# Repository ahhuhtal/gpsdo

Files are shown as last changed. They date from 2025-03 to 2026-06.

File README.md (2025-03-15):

# GPS discliplined oscillator

Contained in this repository are the source code and PCB design files for my GPS disciplined oscillator project.

The GPSDO uses the one pulse per second (PPS) output of a GPS receiver to continuously adjust an OSC5A2B02 oven-controller crystal oscillator to keep it phase-locked with GPS time.

This gives a stable (both short term and long) 10 MHz time base for measurement instruments.

An important design goal has been to keep the cost very low.

Some more information is available at https://kiedontaa.blogspot.com/2025/02/gps-disciplined-oscillator-part-2.html

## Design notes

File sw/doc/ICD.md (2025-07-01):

# Interface control documentation

Several messages pass between the components of the GPSDO system. The contents of those messages are described here.

## I2C

I2C messages are passed between the 4 microcontrollers which make up the system. Each controller has the ability to pull data from or push data to other controllers (act as a master), or have data pushed to or pulled from them (act as a slave).

Fields are described in the order they are transferred. All multi-byte fields are transferred as little-endian. All structures are packed without padding. 

### PPS message

- Type: master push
- 8-bit address: 0x10
- Master: `iface`
- Slave: `pfd`

Message structure:
```
uint32_t timestamp
uint8_t fix
```

`timestamp` is the unix timestamp of the received PPS pulse (seconds since 1970-01-01).

`fix` is 1 when the PPS was produced with full GNSS position fix. Any other value indicates that the PPS was produced without a valid fix.

### OCXO control message

- Type: master push
- 8-bit address: 0x0c
- Master: `pfd`
- Slave: `ocxo_ctrl`

Message structure:
```
int16_t control_word
```

`control_word` determines the frequency adjustment applied to the OCXO. The full scale is available for adjustment. An LSB corresponds with approximately 115 microHertz of frequency adjustment, or about 19 microvolts of control voltage.

### GNSS status message

- Type: master pull
- 8-bit address: 0x03
- Master: `lcd`
- Slave: `iface`

Message structure:
```
uint32_t timestamp
int32_t latitude
int32_t longitude
uint8_t nsat_fix_valid
```

`timestamp` is the unix timestamp of the last GNSS position fix (seconds since 1970-01-01).

`latitude` and `longitude` are the latitude and longitude of the last GNSS position fix as a fraction of 360 degrees, given in fixed point Q0.31 format (sign bit and 31 bits of fraction). Example: `degrees_latitude = latitude / 2**31 * 360.0`. Positive values of `latitude` indicate North, while positive values of `longitude` indicate East. 

Bit 7 of `nsat_fix_valid` indicates validity of the message. The message becomes invalid if the contents are older than 4 seconds.

Bit 6 of `nsat_fix_valid` indicates whether a GNSS position fix is valid (1) or not (0). A valid fix means that the latitude, longitude and timestamp values are valid.

Bits[5:0] of `nsat_fix_valid` indicate the number of satellites used in the last position fix. The value is interpreted as an unsigned integer in the range 0-63.

### Timing status message

- Type: master pull
- 8-bit address: 0x11
- Master: `lcd`
- Slave: `pfd`

Message structure:
```
int32_t phase_error_raw
int32_t phase_error_filtered
int32_t frequecy_error_raw
int32_t frequency_error_filtered
uint32_t time_since_valid
int16_t ocxo_control_word
uint8_t control_mode
```

`phase_error_raw` is the raw estimated phase error from the latest estimation period. `phase_error_filtered` is the filtered phase error, which is a low-pass filtered version of `phase_error_raw`. Both values are in fixed point Q7.24 format (sign bit, 7 bits of integer and 24 bits of fraction). The LSB of these values is approximately 3.0 fs (femtoseconds).

`frequency_error_raw` is the raw estimated frequency error from the latest estimation period. `frequency_error_filtered` is the filtered frequency error, which is a low-pass filtered version of `frequency_error_raw`. Both values are in fixed point Q7.24 format (sign bit, 7 bits of integer and 24 bits of fraction). The LSB of these values is approximately 29.8 nHz (nanohertz).

`time_since_valid` is the time in seconds since a PPS pulse passed full validation.

`ocxo_control_word` is the latest control word sent to the OCXO controller. It is in the same format as the `control_word` field of the OCXO control message.

`control_mode` indicates the current control mode of the system. A value of 0 indicates that the system is in FLL mode, while a value of 1 indicates that the system is in PLL mode. The system starts up in FLL mode and switches to PLL mode once the frequency error has been sufficiently reduced.

### OCXO status message

- Type: master pull
- 8-bit address: 0x0d
- Master: `lcd`
- Slave: `ocxo_ctrl`

Message structure:
```
int16_t temperature
```

`temperature` is the measured temperature of the OCXO. It is in Q11.4 format (sign bit, 11 bits of integer part, 4 bits of fraction) and is given in degrees Celsius. The LSB of this value is 0.0625 degrees Celsius. Example: `temperature_degrees = temperature / 16.0`.

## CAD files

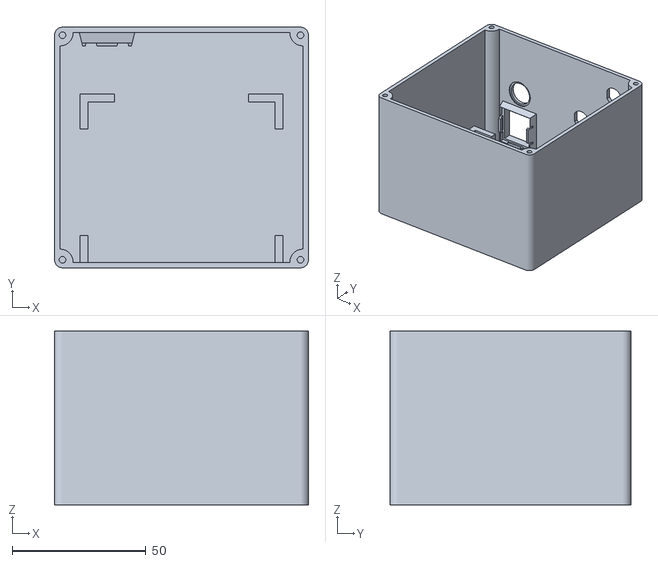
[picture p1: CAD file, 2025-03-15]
mechanics/main_unit/box_bottom.stl
95.0 x 90.0 x 65.0

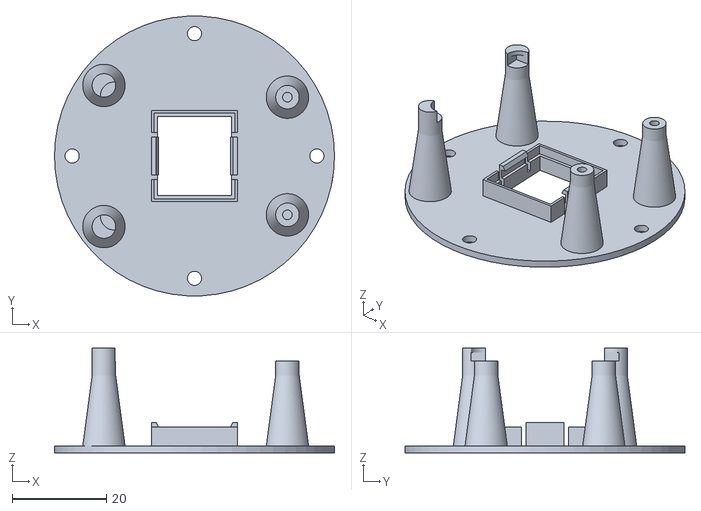
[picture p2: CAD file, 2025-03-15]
mechanics/receiver_unit/bottom_plate.stl
59.5 x 59.4 x 22.3

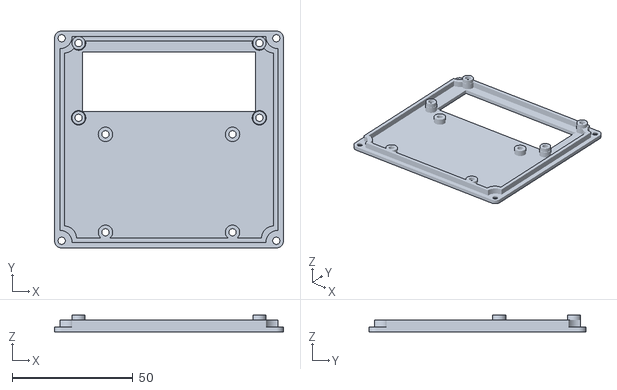
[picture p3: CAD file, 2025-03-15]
mechanics/main_unit/box_lid.stl
95.0 x 90.0 x 7.00

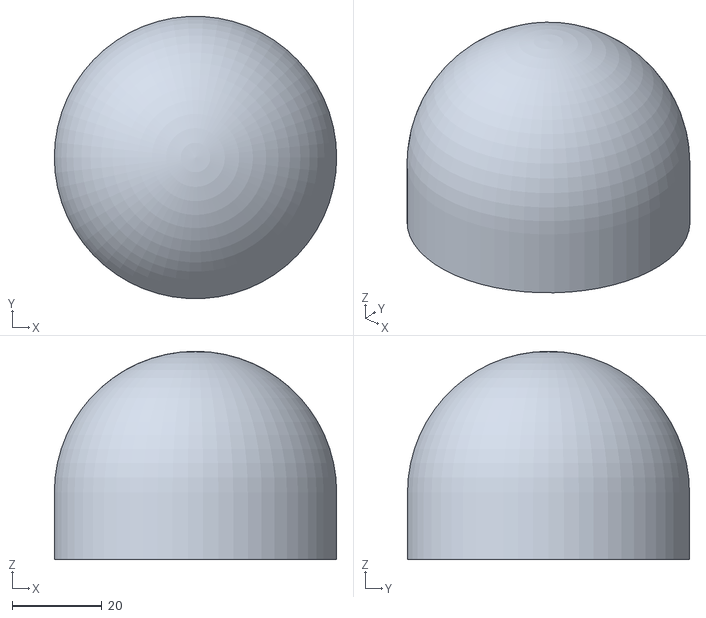
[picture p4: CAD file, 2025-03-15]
mechanics/receiver_unit/dome.stl
63.0 x 62.9 x 46.5

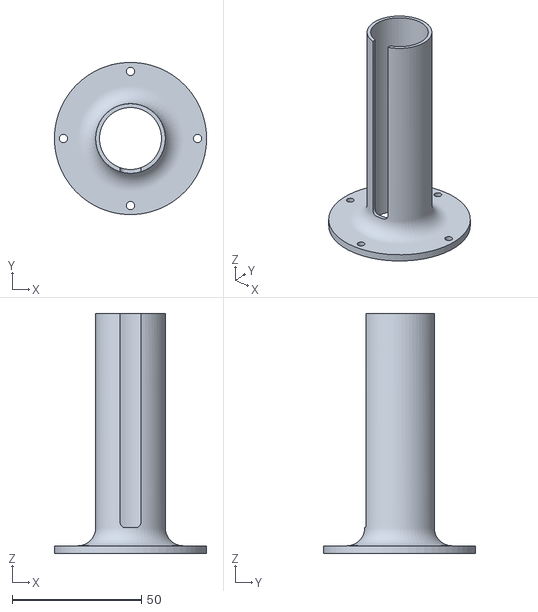
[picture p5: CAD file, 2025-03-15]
mechanics/receiver_unit/pole_mount.stl
59.0 x 58.9 x 93.0

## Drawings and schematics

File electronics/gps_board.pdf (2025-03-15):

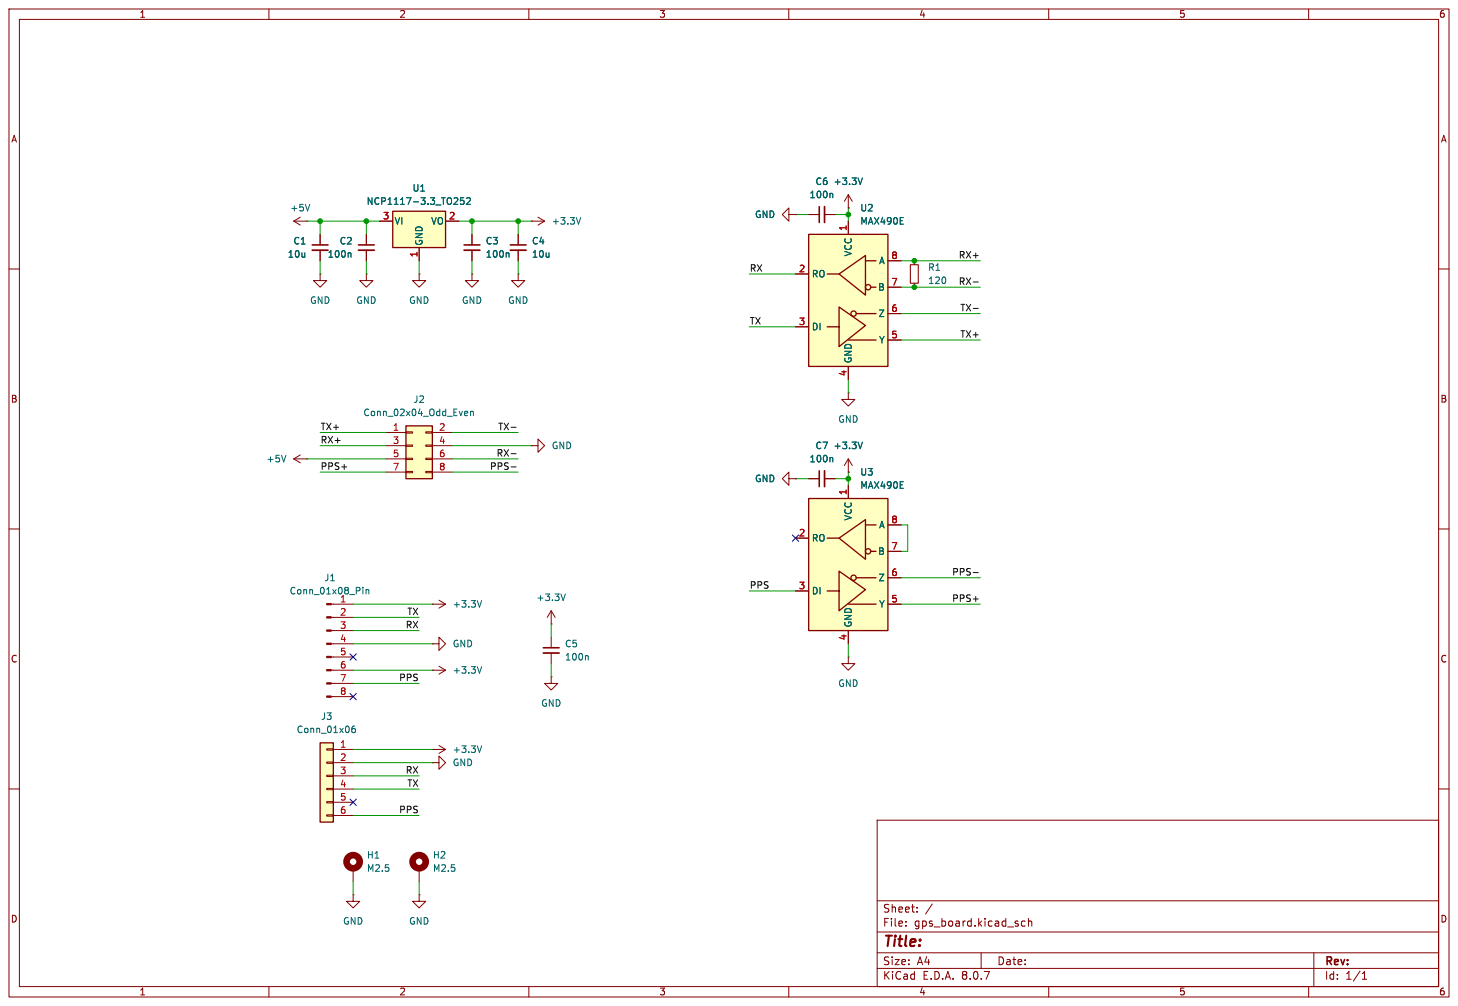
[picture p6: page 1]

Id: 1/1 Title: File: gps_board.kicad_sch Sheet: / H1 M2.5

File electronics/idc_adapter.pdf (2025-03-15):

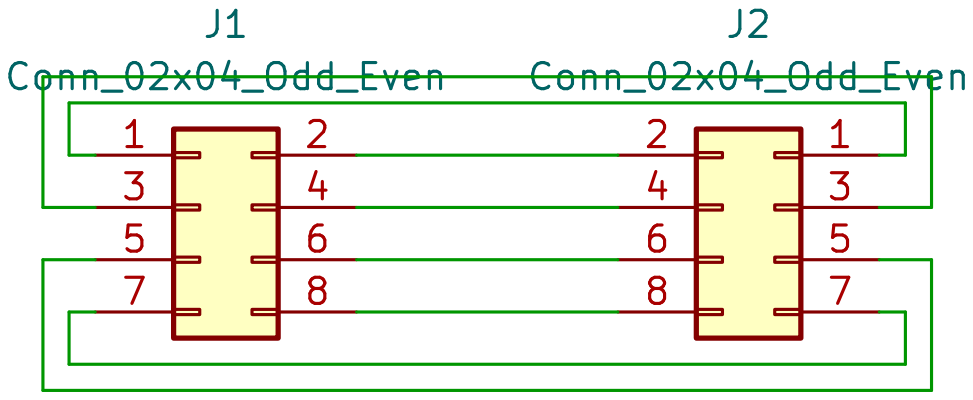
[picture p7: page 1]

Id: 1/1 Title: File: idc_adapter.kicad_sch Sheet: /

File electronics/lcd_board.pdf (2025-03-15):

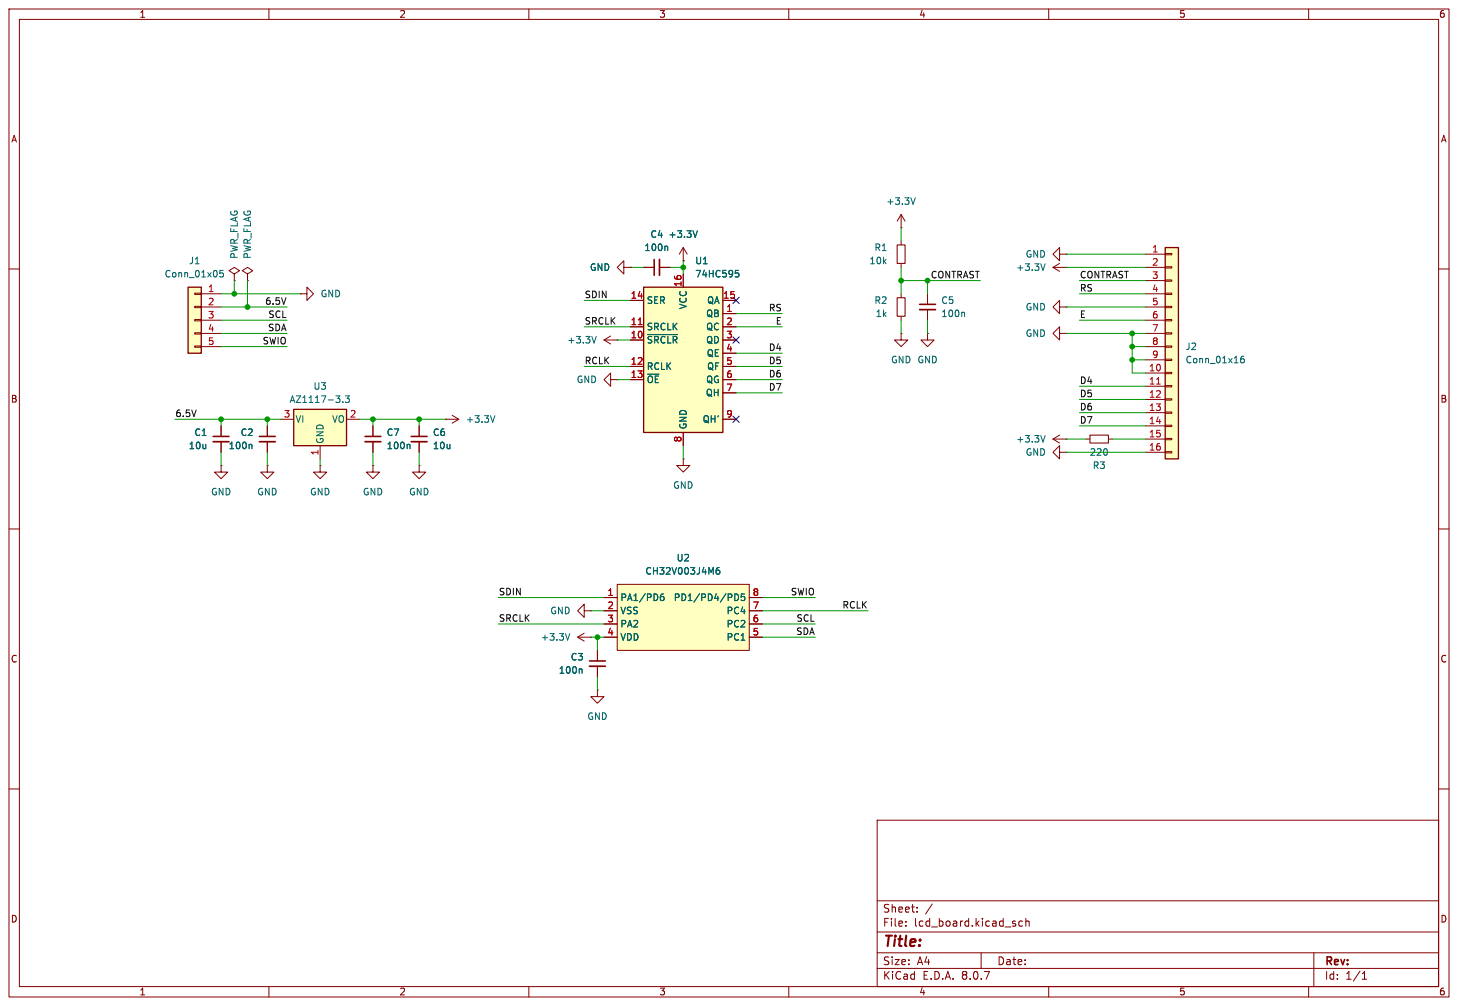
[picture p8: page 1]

Id: 1/1 Title: File: lcd_board.kicad_sch Sheet: /

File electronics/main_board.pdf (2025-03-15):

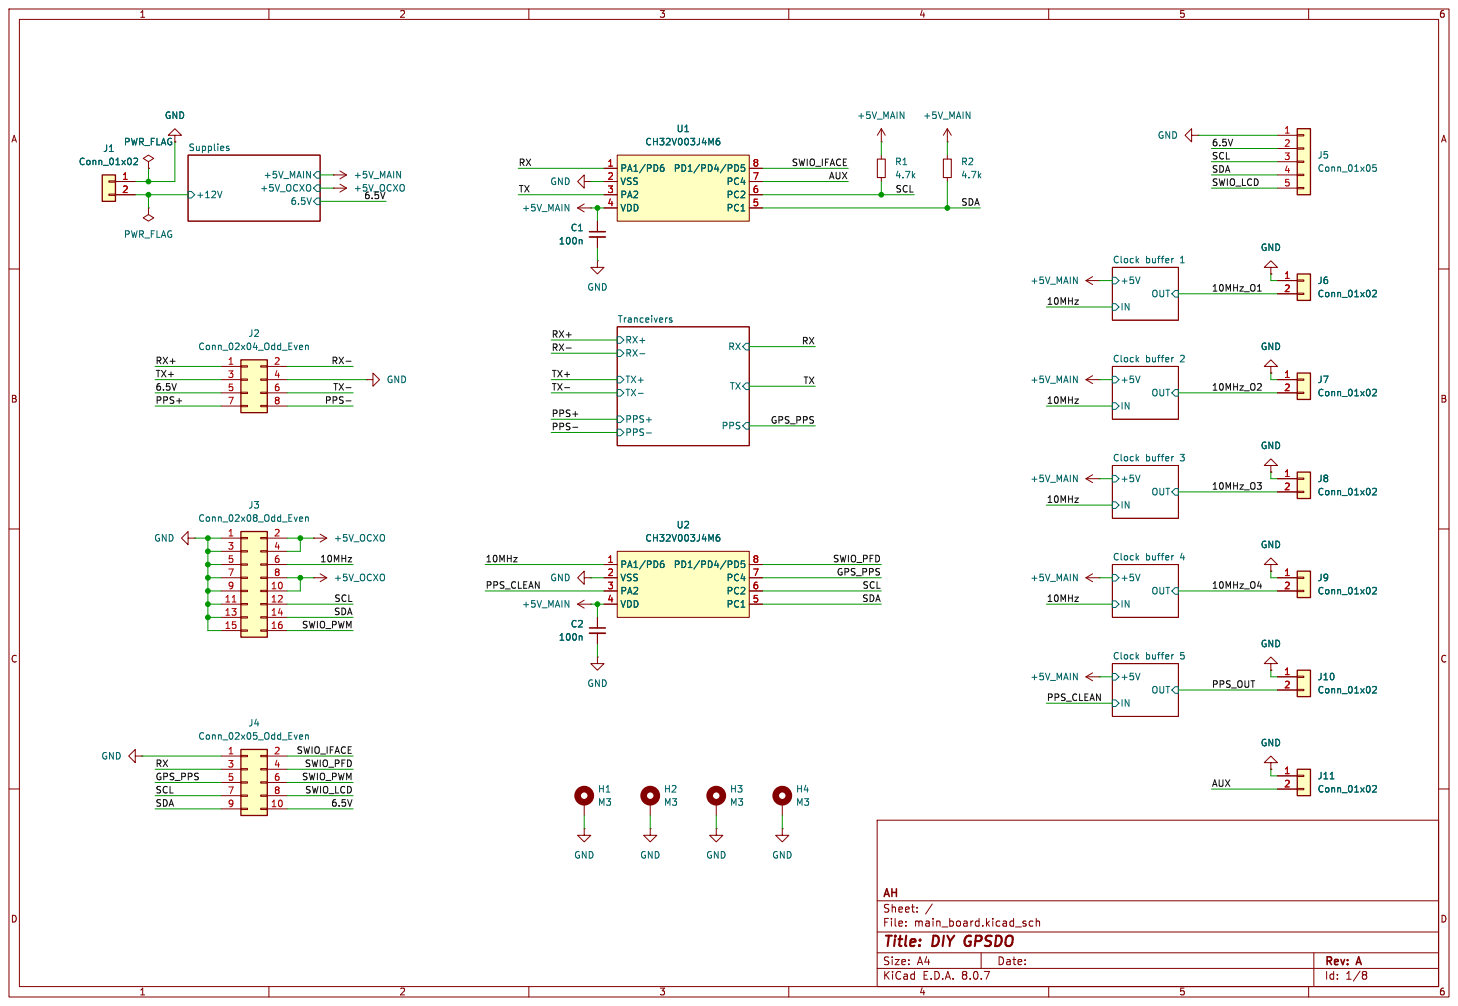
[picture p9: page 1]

Id: 1/8 Title: DIY GPSDO

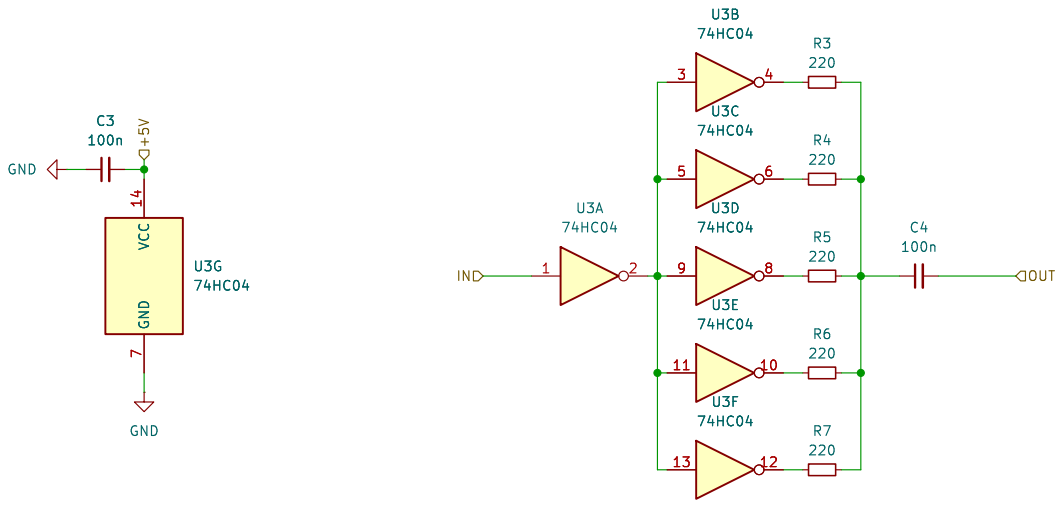
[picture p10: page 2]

Id: 2/8 Title: DIY GPSDO

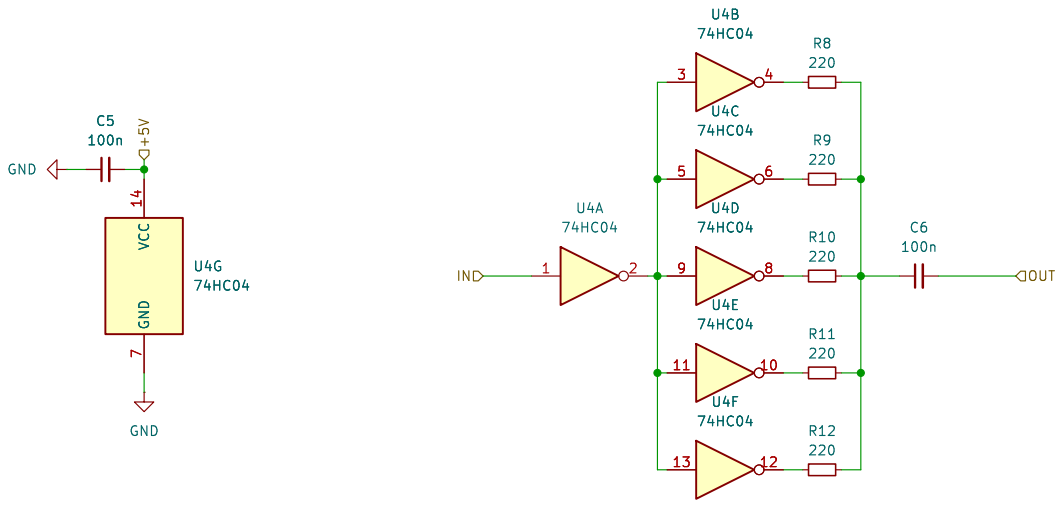
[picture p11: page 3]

Id: 3/8 Title: DIY GPSDO

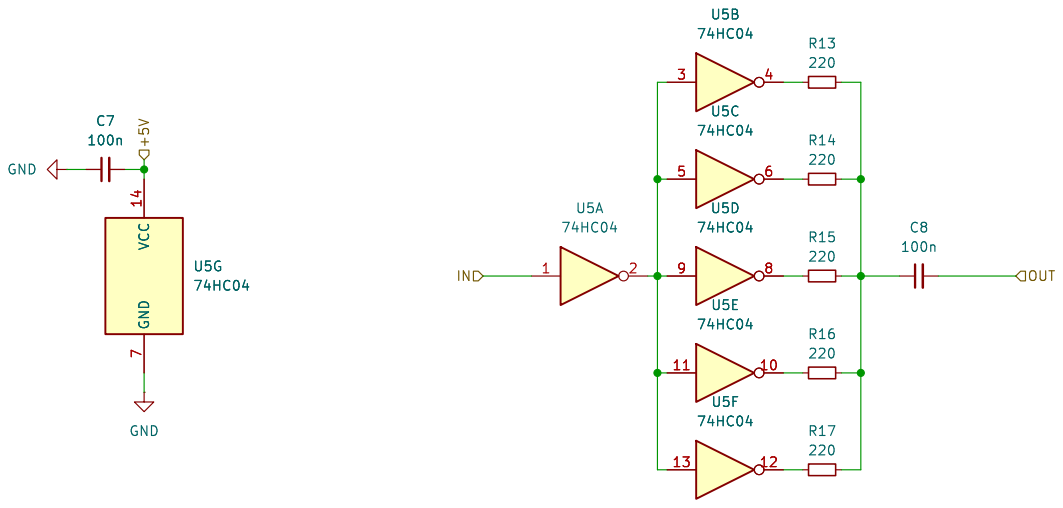
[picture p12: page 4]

Id: 4/8 Title: DIY GPSDO

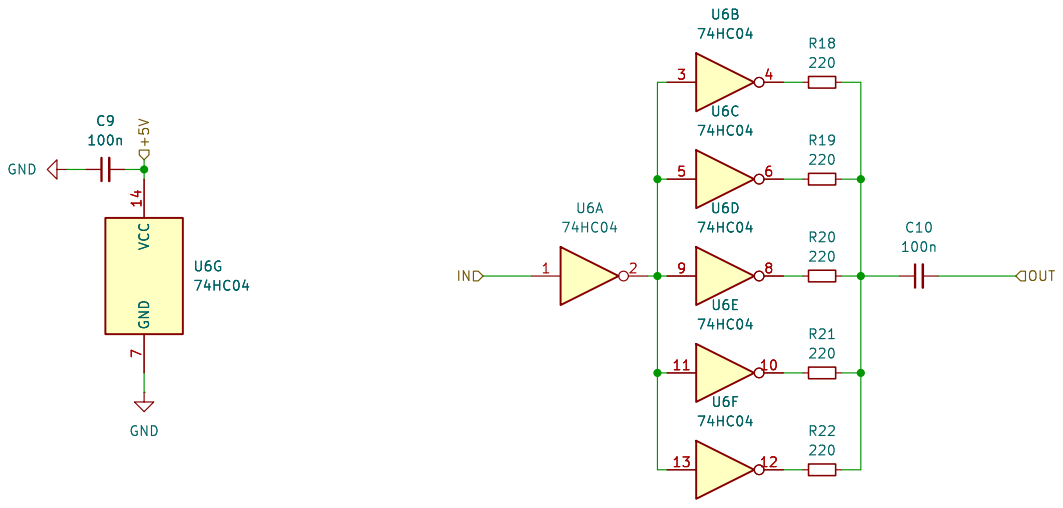
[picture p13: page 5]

Id: 5/8 Title: DIY GPSDO

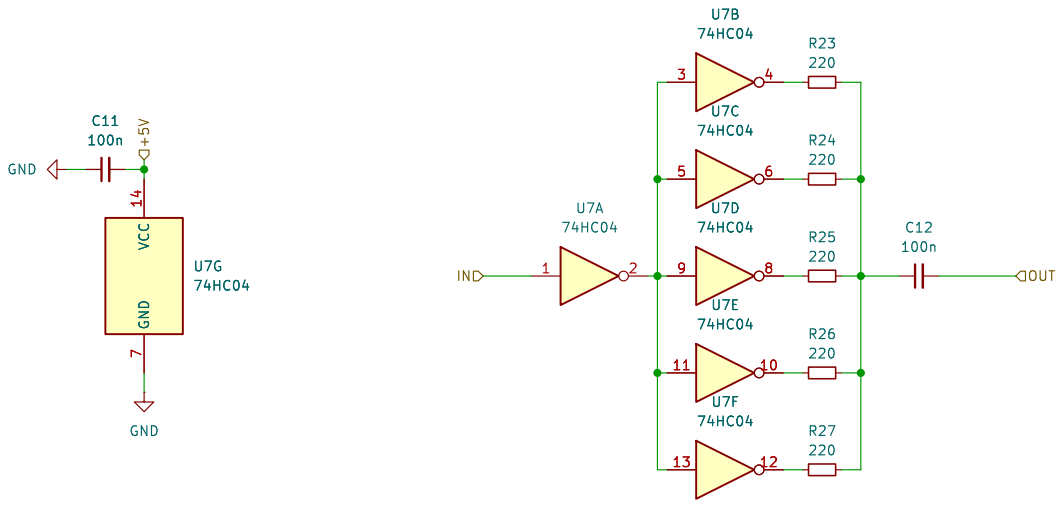
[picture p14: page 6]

Id: 6/8 Title: DIY GPSDO

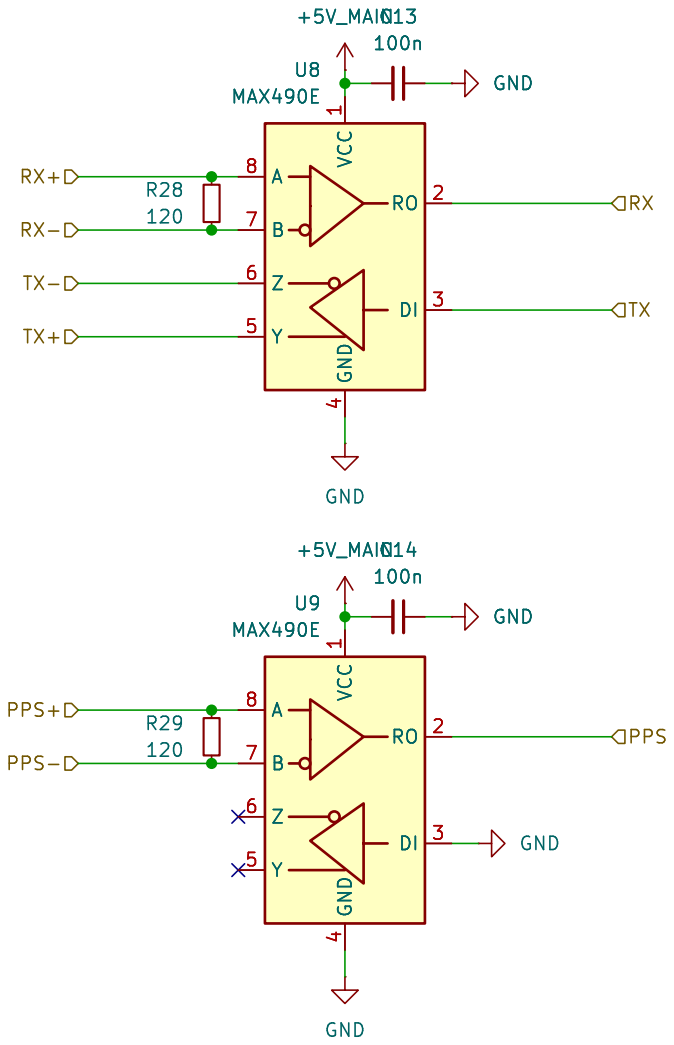
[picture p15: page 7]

Id: 7/8 Title: DIY GPSDO

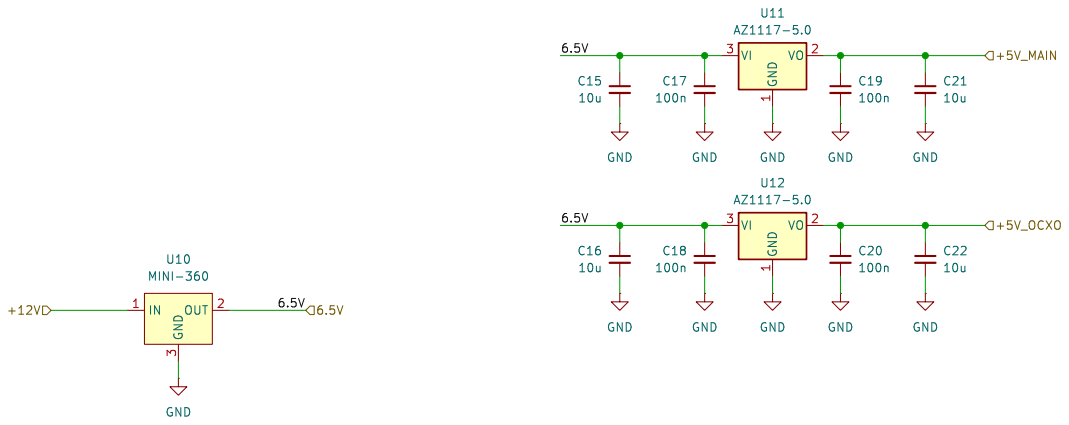
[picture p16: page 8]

1 VO 2 VI 3 U11 AZ1117-5.0 GND GND

Power supplies
File: supplies.kicad_sch Sheet: /Supplies/ AH

Id: 8/8 Title: DIY GPSDO

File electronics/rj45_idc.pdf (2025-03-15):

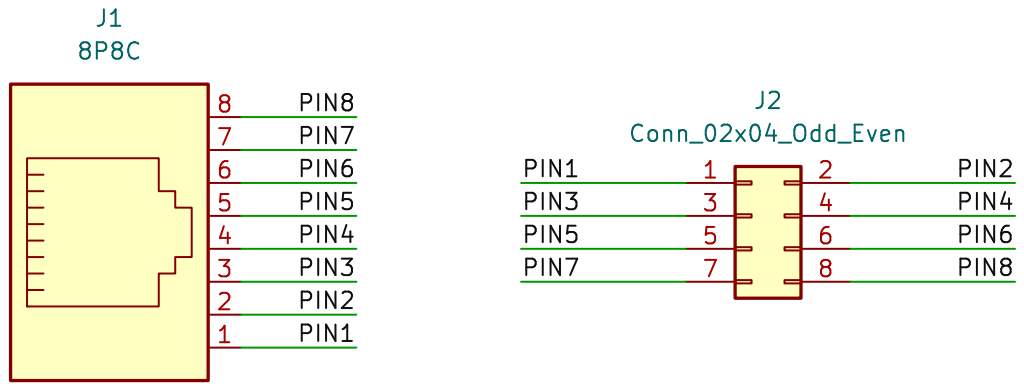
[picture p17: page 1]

Id: 1/1 Title: File: rj45_idc.kicad_sch Sheet: /


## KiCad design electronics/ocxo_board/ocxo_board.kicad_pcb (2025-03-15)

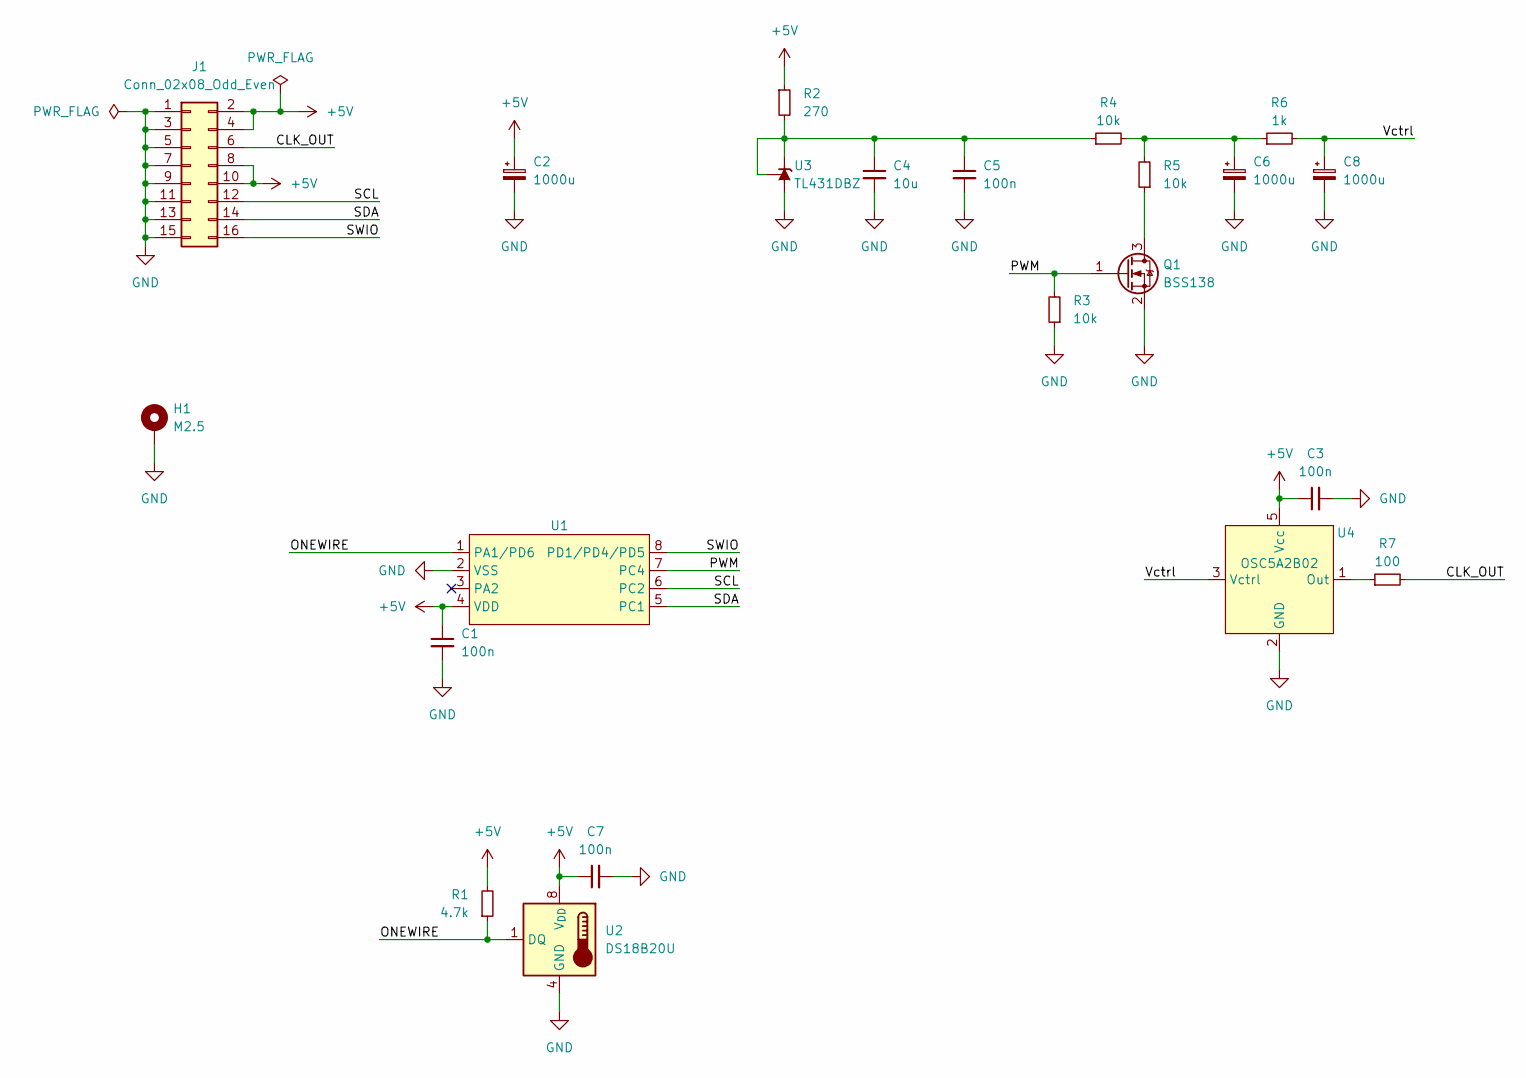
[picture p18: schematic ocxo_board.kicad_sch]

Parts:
C1, C3, C5, C7: 100n; C_0805_2012Metric_Pad1.18x1.45mm_HandSolder
C2, C6, C8: 1000u; CP_Radial_D8.0mm_P3.50mm
C4: 10u; C_0805_2012Metric_Pad1.18x1.45mm_HandSolder
H1: M2.5; MountingHole_2.7mm_M2.5_DIN965_Pad
J1: Conn_02x08_Odd_Even; IDC-Header_2x08_P2.54mm_Vertical
Q1: BSS138; SOT-23
R1: 4.7k; R_0805_2012Metric_Pad1.20x1.40mm_HandSolder
R2: 270; R_0805_2012Metric_Pad1.20x1.40mm_HandSolder
R3, R4, R5: 10k; R_0805_2012Metric_Pad1.20x1.40mm_HandSolder
R6: 1k; R_0805_2012Metric_Pad1.20x1.40mm_HandSolder
R7: 100; R_0805_2012Metric_Pad1.20x1.40mm_HandSolder
U1: SOP-8_3.9x4.9mm_P1.27mm
U2: DS18B20U; MSOP-8_3x3mm_P0.65mm
U3: TL431DBZ; SOT-23
U4: OSC5A2B02

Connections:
+5V: C1.1, C2.1, C3.1, C7.1, J1.2, J1.4, J1.8, J1.10, R1.2, R2.1, U1.4 (VDD), U2.8 (V_{DD}), U4.5 (Vcc)
/CLK_OUT: J1.6, R7.2
/ONEWIRE: R1.1, U1.1 (PA1/PD6), U2.1 (DQ)
/PWM: Q1.1 (G), R3.2, U1.7 (PC4)
/SCL: J1.12, U1.6 (PC2)
/SDA: J1.14, U1.5 (PC1)
/SWIO: J1.16, U1.8 (PD1/PD4/PD5)
/Vctrl: C8.1, R6.2, U4.3 (Vctrl)
GND: C1.2, C2.2, C3.2, C4.2, C5.2, C6.2, C7.2, C8.2, H1.1, J1.1, J1.3, J1.5, J1.7, J1.9, J1.11, J1.13, J1.15, Q1.2 (S), R3.1, U1.2 (VSS), U2.4 (GND), U3.3 (A), U4.2 (GND)
unnamed: C6.1, R4.2, R5.2, R6.1
unnamed: Q1.3 (D), R5.1
unnamed: C4.1, C5.1, R2.2, R4.1, U3.1 (K), U3.2 (REF)
unnamed: R7.1, U4.1 (Out)

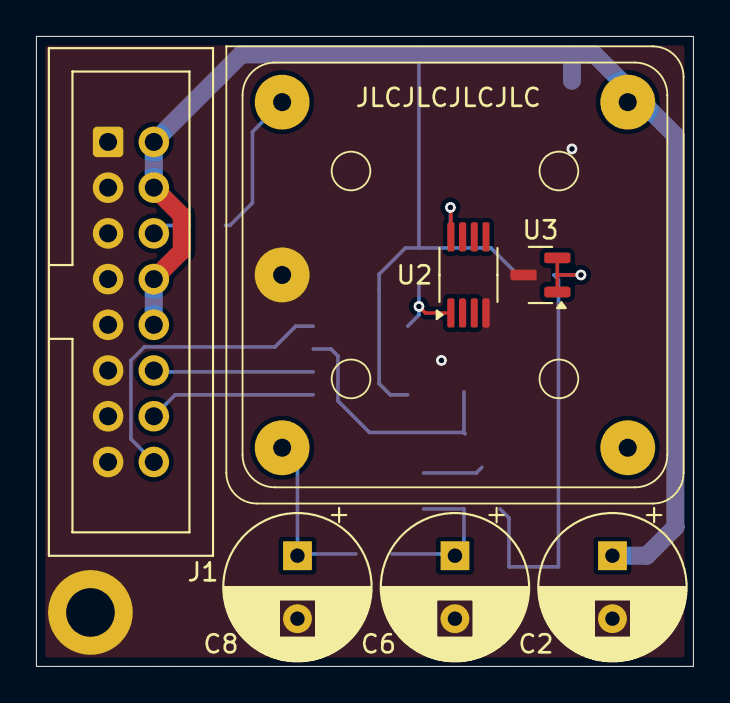
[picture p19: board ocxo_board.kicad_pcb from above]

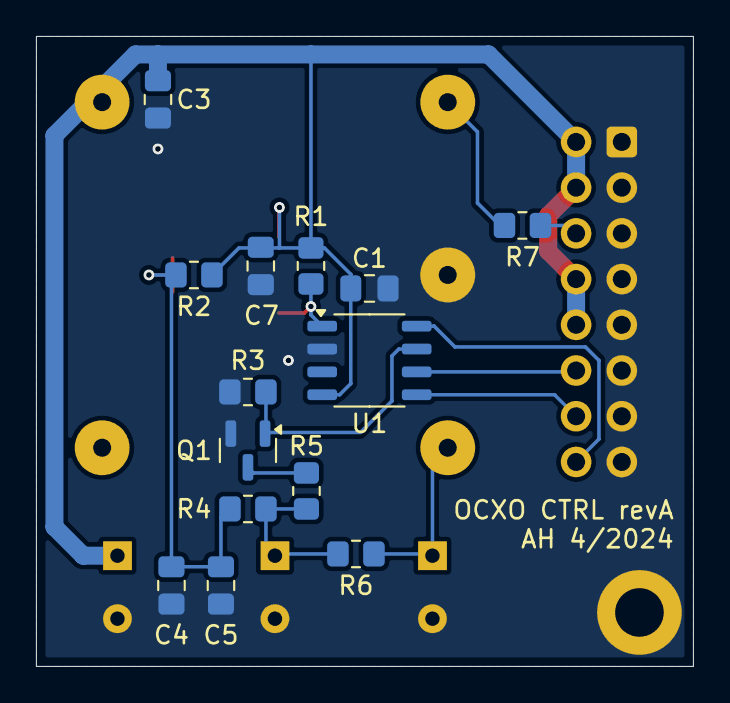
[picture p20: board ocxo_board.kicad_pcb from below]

Board: 2 copper layers, 36.5 x 35.0 mm, 22 parts (14 on the bottom side), 13 nets.

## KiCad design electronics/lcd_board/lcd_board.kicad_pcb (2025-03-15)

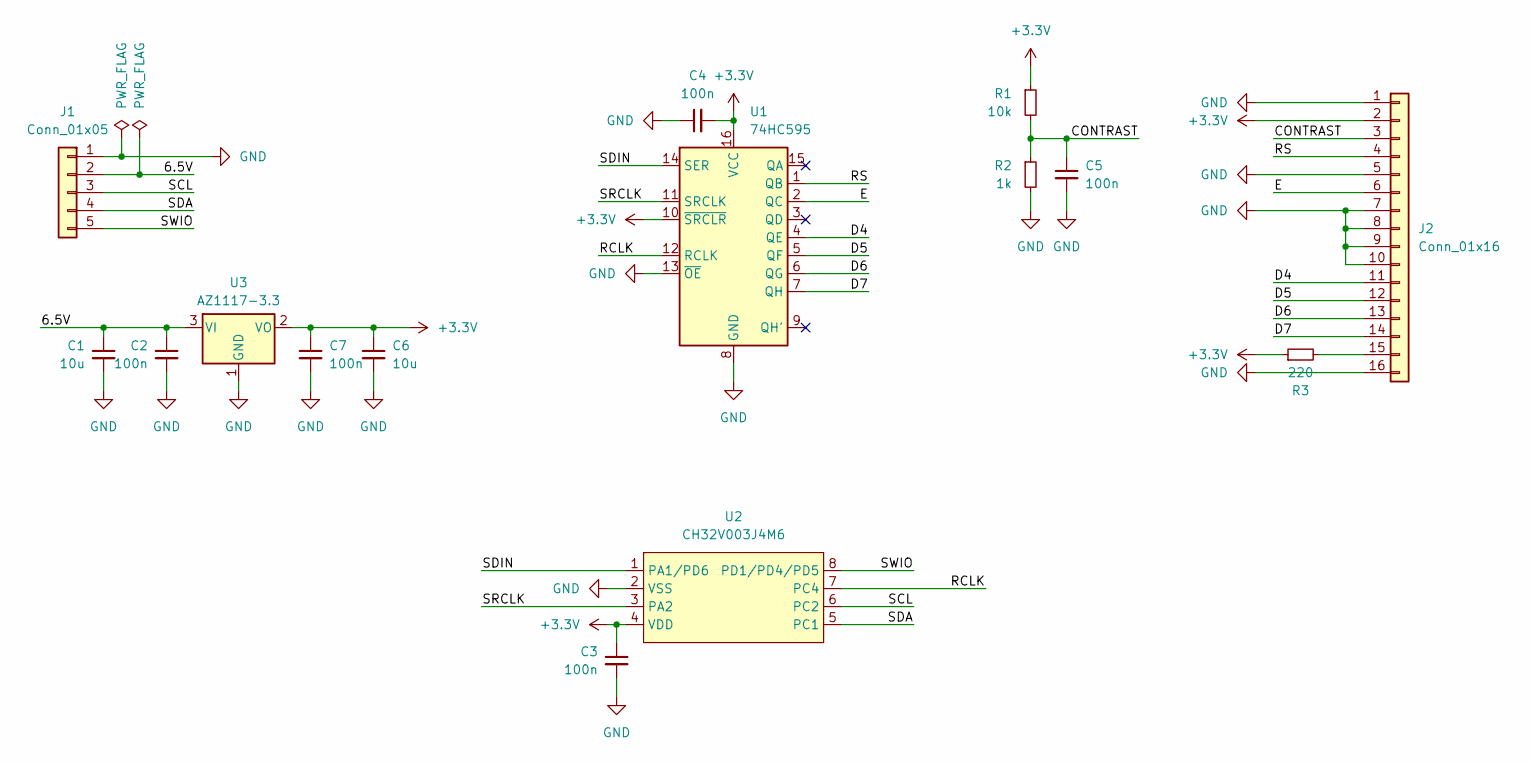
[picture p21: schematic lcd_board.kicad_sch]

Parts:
C1, C6: 10u; C_0805_2012Metric_Pad1.18x1.45mm_HandSolder
C2, C3, C4, C5, C7: 100n; C_0805_2012Metric_Pad1.18x1.45mm_HandSolder
J1: Conn_01x05; JST_PH_B5B-PH-K_1x05_P2.00mm_Vertical
J2: Conn_01x16; PinHeader_1x16_P2.54mm_Vertical
R1: 10k; R_0805_2012Metric_Pad1.20x1.40mm_HandSolder
R2: 1k; R_0805_2012Metric_Pad1.20x1.40mm_HandSolder
R3: 220; R_0805_2012Metric_Pad1.20x1.40mm_HandSolder
U1: 74HC595; SOIC-16_3.9x9.9mm_P1.27mm
U2: CH32V003J4M6; SOP-8_3.9x4.9mm_P1.27mm
U3: AZ1117-3.3; SOT-223-3_TabPin2

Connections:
+3.3V: C3.1, C4.2, C6.1, C7.1, J2.2, R1.1, R3.1, U1.10 (~SRCLR), U1.16 (VCC), U2.4 (VDD), U3.2 (VO)
/6.5V: C1.1, C2.1, J1.2, U3.3 (VI)
/CONTRAST: C5.1, J2.3, R1.2, R2.1
/D4: J2.11, U1.4 (QE)
/D5: J2.12, U1.5 (QF)
/D6: J2.13, U1.6 (QG)
/D7: J2.14, U1.7 (QH)
/E: J2.6, U1.2 (QC)
/RCLK: U1.12 (RCLK), U2.7 (PC4)
/RS: J2.4, U1.1 (QB)
/SCL: J1.3, U2.6 (PC2)
/SDA: J1.4, U2.5 (PC1)
/SDIN: U1.14 (SER), U2.1 (PA1/PD6)
/SRCLK: U1.11 (SRCLK), U2.3 (PA2)
/SWIO: J1.5, U2.8 (PD1/PD4/PD5)
GND: C1.2, C2.2, C3.2, C4.1, C5.2, C6.2, C7.2, J1.1, J2.1, J2.5, J2.7, J2.8, J2.9, J2.10, J2.16, R2.2, U1.8 (GND), U1.13 (~OE), U2.2 (VSS), U3.1 (GND)
unnamed: J2.15, R3.2

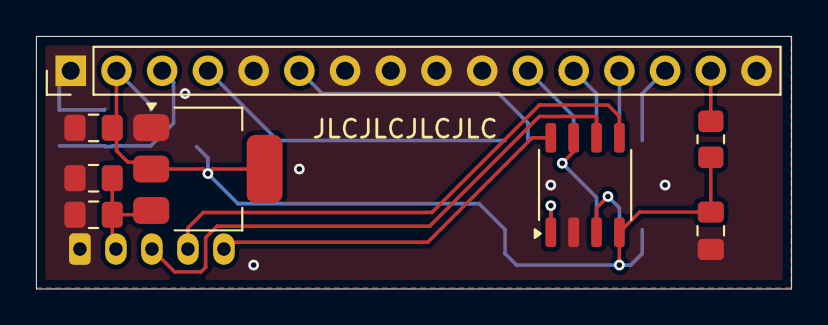
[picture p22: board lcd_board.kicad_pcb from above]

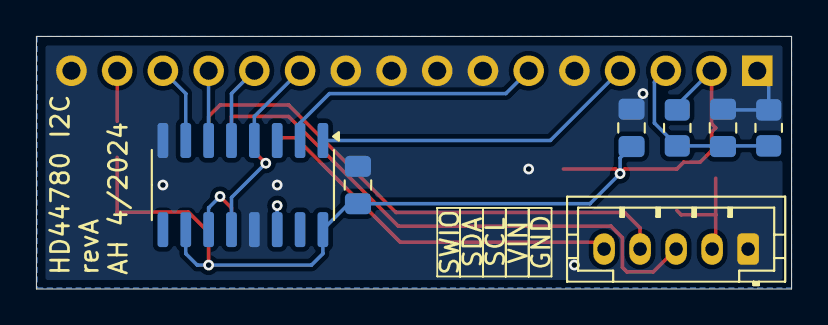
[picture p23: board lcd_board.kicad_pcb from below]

Board: 2 copper layers, 41.9 x 14.0 mm, 15 parts (7 on the bottom side), 17 nets.

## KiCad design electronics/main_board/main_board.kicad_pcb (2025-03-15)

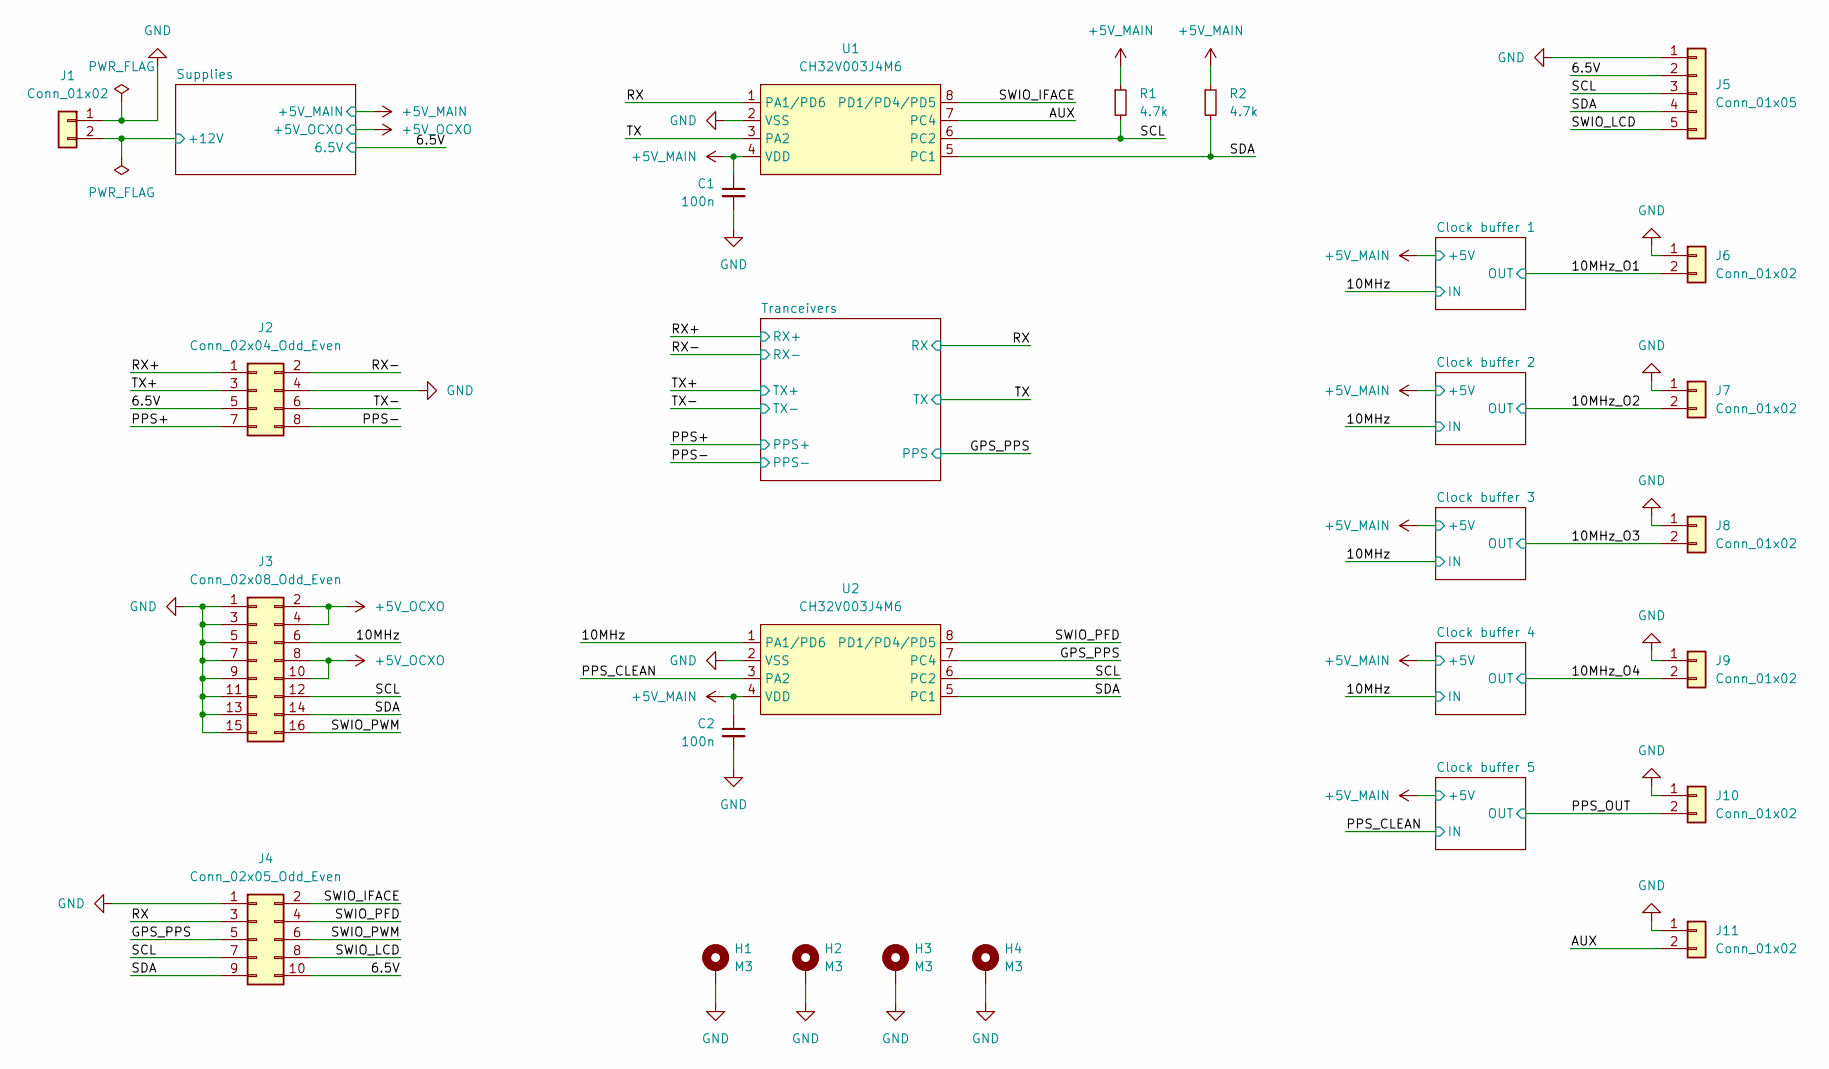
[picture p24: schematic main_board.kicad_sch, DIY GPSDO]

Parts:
C1, C2: 100n; C_0805_2012Metric_Pad1.18x1.45mm_HandSolder
H1, H2, H3, H4: M3; MountingHole_3.2mm_M3_DIN965_Pad
J1, J6, J7, J8, J9, J10, J11: Conn_01x02; JST_PH_B2B-PH-K_1x02_P2.00mm_Vertical
J2: Conn_02x04_Odd_Even; IDC-Header_2x04_P2.54mm_Vertical
J3: Conn_02x08_Odd_Even; IDC-Header_2x08_P2.54mm_Vertical
J4: Conn_02x05_Odd_Even; IDC-Header_2x05_P2.54mm_Vertical
J5: Conn_01x05; JST_PH_B5B-PH-K_1x05_P2.00mm_Vertical
R1, R2: 4.7k; R_0805_2012Metric_Pad1.20x1.40mm_HandSolder
U1, U2: CH32V003J4M6; SOP-8_3.9x4.9mm_P1.27mm

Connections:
+5V_MAIN: C1.1, C2.1, R1.1, R2.1, U1.4 (VDD), U2.4 (VDD); also elsewhere on the board
+5V_OCXO: J3.2, J3.4, J3.8, J3.10; also elsewhere on the board
/6.5V: J2.5, J4.10, J5.2; also elsewhere on the board
/10MHz: J3.6, U2.1 (PA1/PD6); also elsewhere on the board
/10MHz_O1: J6.2; also elsewhere on the board
/10MHz_O2: J7.2; also elsewhere on the board
/10MHz_O3: J8.2; also elsewhere on the board
/10MHz_O4: J9.2; also elsewhere on the board
/AUX: J11.2, U1.7 (PC4)
/GPS_PPS: J4.5, U2.7 (PC4); also elsewhere on the board
/PPS+: J2.7; also elsewhere on the board
/PPS-: J2.8; also elsewhere on the board
/PPS_CLEAN: U2.3 (PA2); also elsewhere on the board
/PPS_OUT: J10.2; also elsewhere on the board
/RX: J4.3, U1.1 (PA1/PD6); also elsewhere on the board
/RX+: J2.1; also elsewhere on the board
/RX-: J2.2; also elsewhere on the board
/SCL: J3.12, J4.7, J5.3, R1.2, U1.6 (PC2), U2.6 (PC2)
/SDA: J3.14, J4.9, J5.4, R2.2, U1.5 (PC1), U2.5 (PC1)
/SWIO_IFACE: J4.2, U1.8 (PD1/PD4/PD5)
/SWIO_LCD: J4.8, J5.5
/SWIO_PFD: J4.4, U2.8 (PD1/PD4/PD5)
/SWIO_PWM: J3.16, J4.6
/Supplies/+12V: J1.2; also elsewhere on the board
/TX: U1.3 (PA2); also elsewhere on the board
/TX+: J2.3; also elsewhere on the board
/TX-: J2.6; also elsewhere on the board
GND: C1.2, C2.2, H1.1, H2.1, H3.1, H4.1, J1.1, J2.4, J3.1, J3.3, J3.5, J3.7, J3.9, J3.11, J3.13, J3.15, J4.1, J5.1, J6.1, J7.1, J8.1, J9.1, J10.1, J11.1, U1.2 (VSS), U2.2 (VSS); also elsewhere on the board

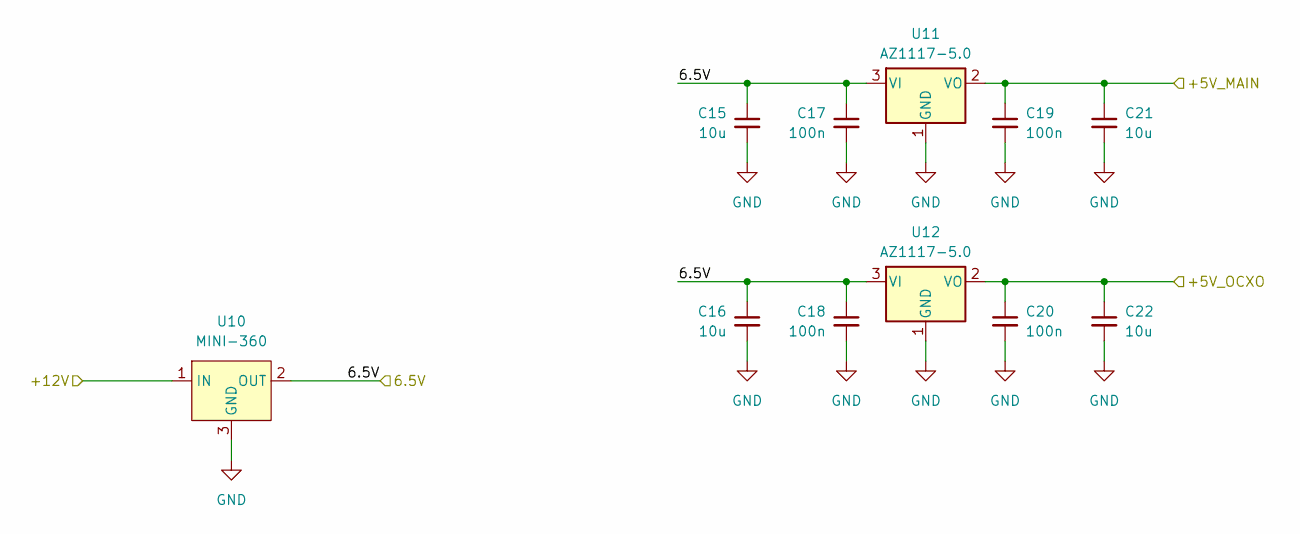
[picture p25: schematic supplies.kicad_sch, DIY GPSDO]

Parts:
C15, C16, C21, C22: 10u; C_0805_2012Metric_Pad1.18x1.45mm_HandSolder
C17, C18, C19, C20: 100n; C_0805_2012Metric_Pad1.18x1.45mm_HandSolder
U10: MINI-360
U11, U12: AZ1117-5.0; TO-252-2

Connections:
+5V_MAIN: C19.1, C21.1, U11.2 (VO); also elsewhere on the board
+5V_OCXO: C20.1, C22.1, U12.2 (VO); also elsewhere on the board
/6.5V: C15.1, C16.1, C17.1, C18.1, U10.2 (OUT), U11.3 (VI), U12.3 (VI); also elsewhere on the board
/Supplies/+12V: U10.1 (IN); also elsewhere on the board
GND: C15.2, C16.2, C17.2, C18.2, C19.2, C20.2, C21.2, C22.2, U10.3 (GND), U11.1 (GND), U12.1 (GND); also elsewhere on the board

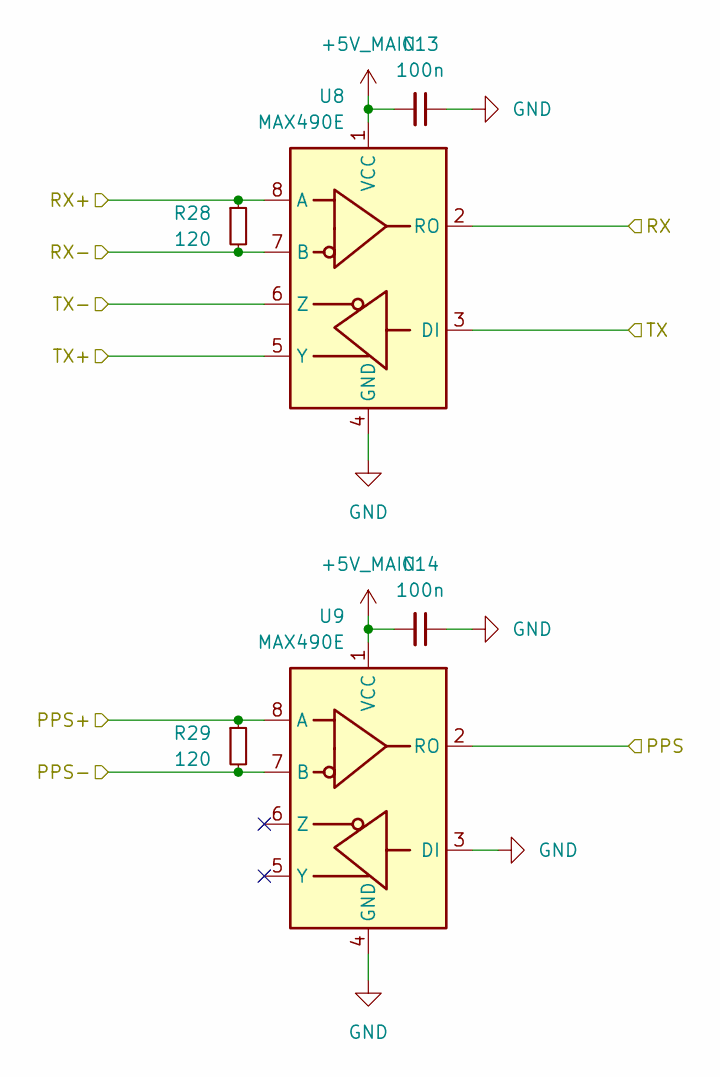
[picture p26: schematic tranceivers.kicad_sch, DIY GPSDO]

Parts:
C13, C14: 100n; C_0805_2012Metric_Pad1.18x1.45mm_HandSolder
R28, R29: 120; R_0805_2012Metric_Pad1.20x1.40mm_HandSolder
U8, U9: MAX490E; SOIC-8_3.9x4.9mm_P1.27mm

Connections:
+5V_MAIN: C13.2, C14.2, U8.1 (VCC), U9.1 (VCC); also elsewhere on the board
/GPS_PPS: U9.2 (RO); also elsewhere on the board
/PPS+: R29.1, U9.8 (A); also elsewhere on the board
/PPS-: R29.2, U9.7 (B); also elsewhere on the board
/RX: U8.2 (RO); also elsewhere on the board
/RX+: R28.1, U8.8 (A); also elsewhere on the board
/RX-: R28.2, U8.7 (B); also elsewhere on the board
/TX: U8.3 (DI); also elsewhere on the board
/TX+: U8.5 (Y); also elsewhere on the board
/TX-: U8.6 (Z); also elsewhere on the board
GND: C13.1, C14.1, U8.4 (GND), U9.3 (DI), U9.4 (GND); also elsewhere on the board

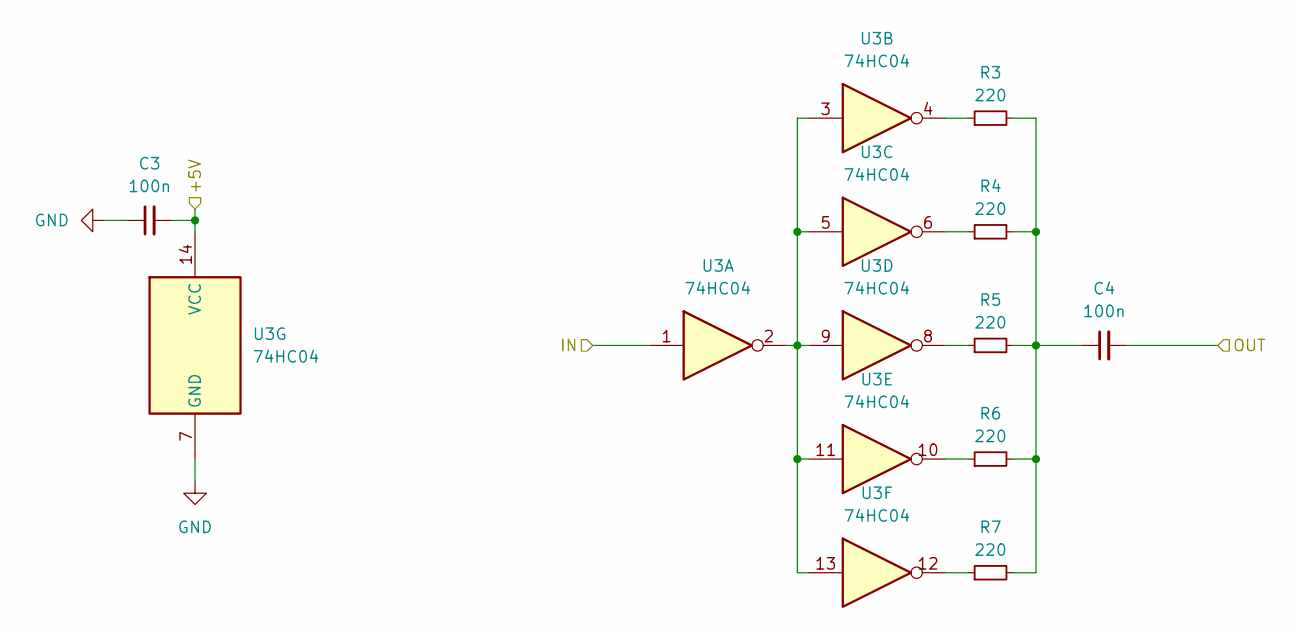
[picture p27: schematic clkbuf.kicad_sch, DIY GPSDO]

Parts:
C3, C4: 100n; C_0805_2012Metric_Pad1.18x1.45mm_HandSolder
R3, R4, R5, R6, R7: 220; R_0805_2012Metric_Pad1.20x1.40mm_HandSolder
U3: 74HC04; SOIC-14_3.9x8.7mm_P1.27mm

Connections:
+5V_MAIN: C3.2, U3.14 (VCC); also elsewhere on the board
/10MHz: U3.1; also elsewhere on the board
/10MHz_O1: C4.2; also elsewhere on the board
GND: C3.1, U3.7 (GND); also elsewhere on the board
unnamed: C4.1, R3.2, R4.2, R5.2, R6.2, R7.2
unnamed: R3.1, U3.4
unnamed: R4.1, U3.6
unnamed: R5.1, U3.8
unnamed: R6.1, U3.10
unnamed: R7.1, U3.12
unnamed: U3.2, U3.3, U3.5, U3.9, U3.11, U3.13

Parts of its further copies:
C5, C6, C7, C8, C9, C10, C11, C12: 100n; C_0805_2012Metric_Pad1.18x1.45mm_HandSolder
R8, R9, R10, R11, R12, R13, R14, R15, R16, R17, R18, R19, R20, R21, R22, R23, R24, R25, R26, R27: 220; R_0805_2012Metric_Pad1.20x1.40mm_HandSolder
U4, U5, U6, U7: 74HC04; SOIC-14_3.9x8.7mm_P1.27mm

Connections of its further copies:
+5V_MAIN: C5.2, C7.2, C9.2, C11.2, U4.14 (VCC), U5.14 (VCC), U6.14 (VCC), U7.14 (VCC); also elsewhere on the board
/10MHz: U4.1, U5.1, U6.1; also elsewhere on the board
/10MHz_O2: C6.2; also elsewhere on the board
/10MHz_O3: C8.2; also elsewhere on the board
/10MHz_O4: C10.2; also elsewhere on the board
/PPS_CLEAN: U7.1; also elsewhere on the board
/PPS_OUT: C12.2; also elsewhere on the board
GND: C5.1, C7.1, C9.1, C11.1, U4.7 (GND), U5.7 (GND), U6.7 (GND), U7.7 (GND); also elsewhere on the board
unnamed: C6.1, R8.2, R9.2, R10.2, R11.2, R12.2
unnamed: C8.1, R13.2, R14.2, R15.2, R16.2, R17.2
unnamed: C10.1, R18.2, R19.2, R20.2, R21.2, R22.2
unnamed: C12.1, R23.2, R24.2, R25.2, R26.2, R27.2
unnamed: R8.1, U4.4
unnamed: R9.1, U4.6
unnamed: R10.1, U4.8
unnamed: R11.1, U4.10
unnamed: R12.1, U4.12
unnamed: R13.1, U5.4
unnamed: R14.1, U5.6
unnamed: R15.1, U5.8
unnamed: R16.1, U5.10
unnamed: R17.1, U5.12
unnamed: R18.1, U6.4
unnamed: R19.1, U6.6
unnamed: R20.1, U6.8
unnamed: R21.1, U6.10
unnamed: R22.1, U6.12
unnamed: R23.1, U7.4
unnamed: R24.1, U7.6
unnamed: R25.1, U7.8
unnamed: R26.1, U7.10
unnamed: R27.1, U7.12
unnamed: U4.2, U4.3, U4.5, U4.9, U4.11, U4.13
unnamed: U5.2, U5.3, U5.5, U5.9, U5.11, U5.13
unnamed: U6.2, U6.3, U6.5, U6.9, U6.11, U6.13
unnamed: U7.2, U7.3, U7.5, U7.9, U7.11, U7.13

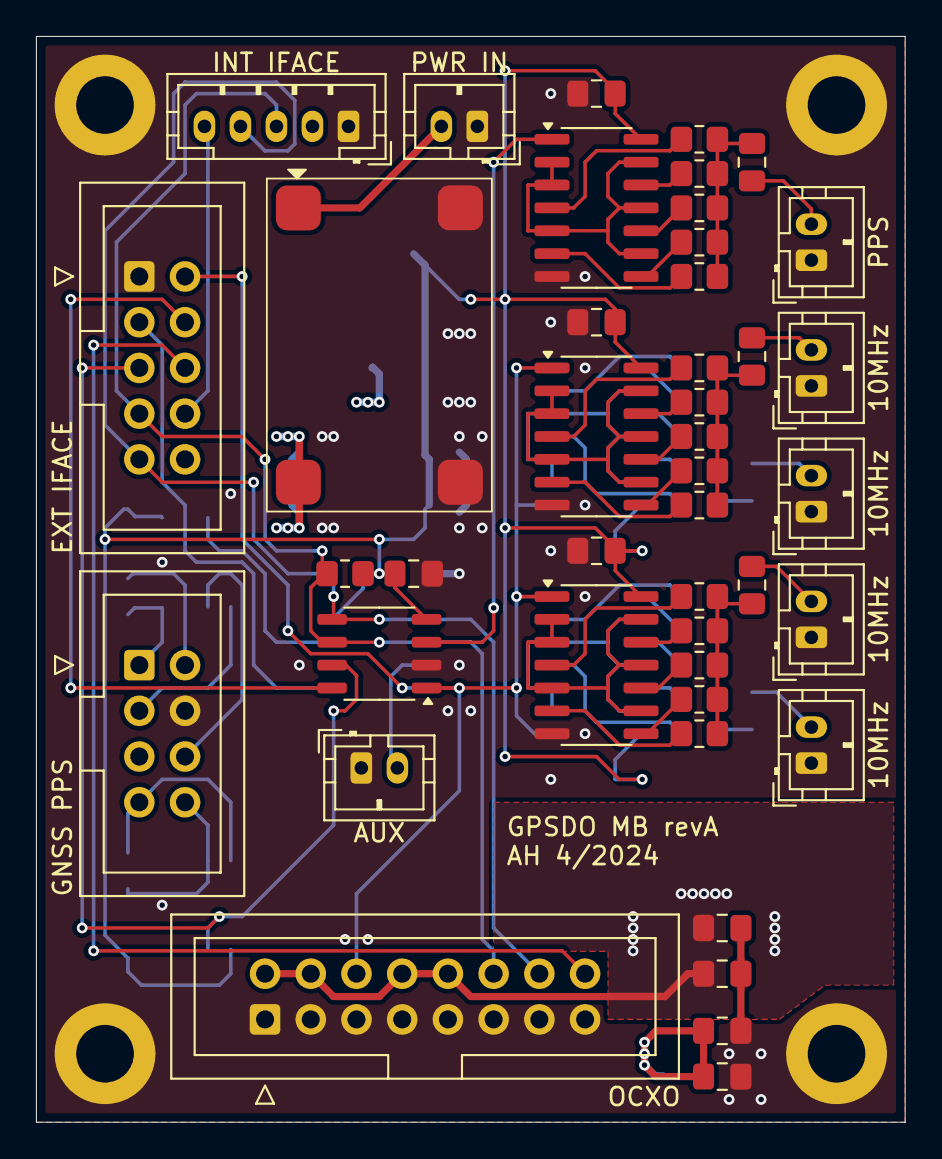
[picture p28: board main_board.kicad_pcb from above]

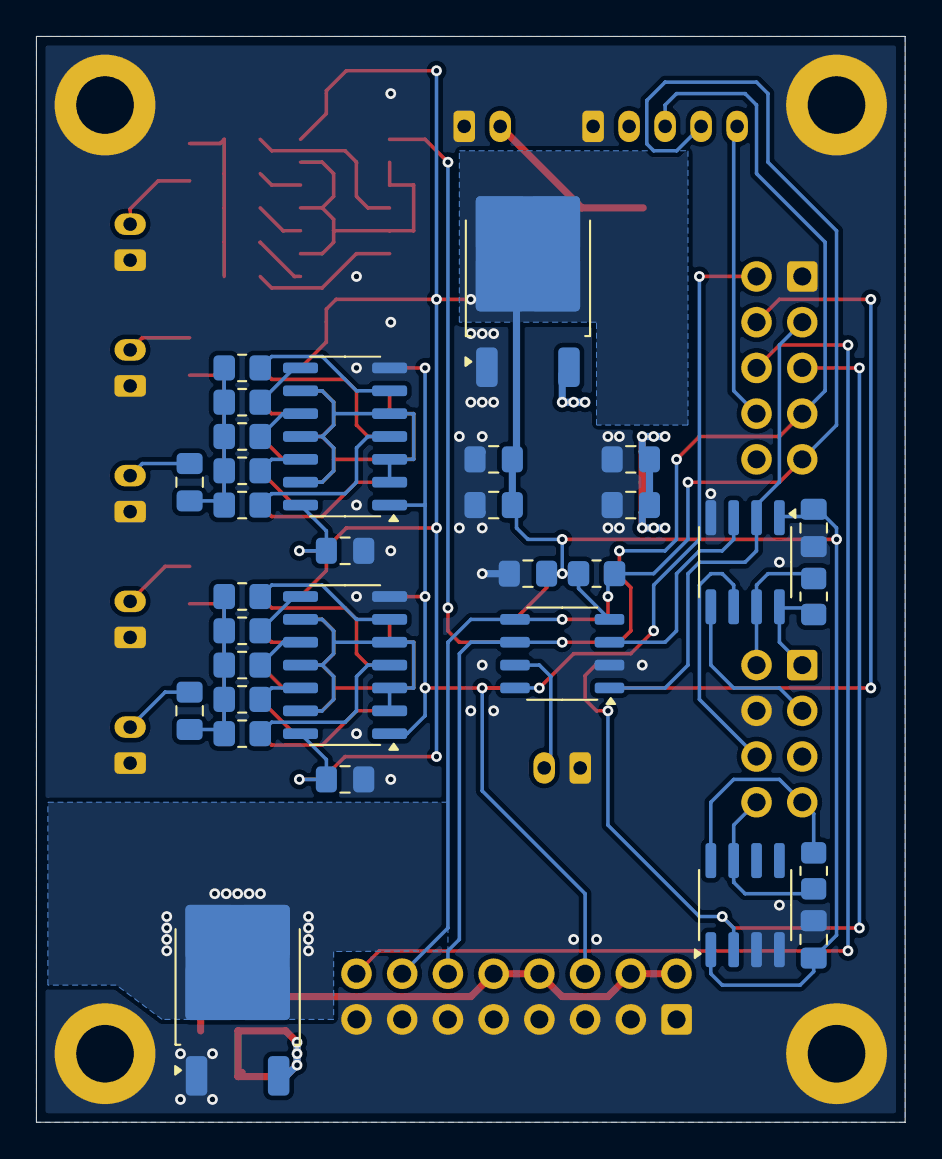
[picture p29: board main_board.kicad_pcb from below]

Board: 4 copper layers, 48.3 x 60.3 mm, 78 parts (31 on the bottom side), 63 nets.

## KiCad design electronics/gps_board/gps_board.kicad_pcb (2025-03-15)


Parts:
C1, C4: 10u; C_0805_2012Metric_Pad1.18x1.45mm_HandSolder
C2, C3, C5, C6, C7: 100n; C_0805_2012Metric_Pad1.18x1.45mm_HandSolder
H1, H2: M2.5; MountingHole_2.7mm_M2.5_DIN965_Pad
J1: Conn_01x08_Pin; PinHeader_1x08_P1.27mm_Vertical
J2: Conn_02x04_Odd_Even; IDC-Header_2x04_P2.54mm_Vertical
J3: Conn_01x06; JST_PH_B6B-PH-K_1x06_P2.00mm_Vertical
R1: 120; R_0805_2012Metric_Pad1.20x1.40mm_HandSolder
U1: NCP1117-3.3_TO252; TO-252-2
U2, U3: MAX490E; SOIC-8_3.9x4.9mm_P1.27mm

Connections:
+3.3V: C3.1, C4.1, C5.1, C6.2, C7.2, J1.1, J1.6, J3.1, U1.2 (VO), U2.1 (VCC), U3.1 (VCC)
+5V: C1.1, C2.1, J2.5, U1.3 (VI)
/PPS: J1.7, J3.6, U3.3 (DI)
/PPS+: J2.7, U3.5 (Y)
/PPS-: J2.8, U3.6 (Z)
/RX: J1.3, J3.3, U2.2 (RO)
/RX+: J2.3, R1.1, U2.8 (A)
/RX-: J2.6, R1.2, U2.7 (B)
/TX: J1.2, J3.4, U2.3 (DI)
/TX+: J2.1, U2.5 (Y)
/TX-: J2.2, U2.6 (Z)
GND: C1.2, C2.2, C3.2, C4.2, C5.2, C6.1, C7.1, H1.1, H2.1, J1.4, J2.4, J3.2, U1.1 (GND), U2.4 (GND), U3.4 (GND)
unnamed: U3.7 (B), U3.8 (A)



Board: 2 copper layers, 42.5 x 31.0 mm, 16 parts (11 on the bottom side), 13 nets.

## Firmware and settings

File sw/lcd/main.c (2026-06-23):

#include <stdio.h>
#include <stdarg.h>
#include <stdbool.h>
#include <limits.h>

#include "i2c.h"
#include "unixtime.h"

#include "ch32fun.h"

int mini_vsnprintf(char *buffer, unsigned int buffer_len, const char *fmt, va_list va);

/*
 * GPSDO LCD board sub-unit software implementation
 *
 * 1. Pulls data from the GNSS interface, PLL controller and OCXO board
 * 2. Controls an HD44780 LCD through a 74HC595 shift register
 *    to display the data for the user.
 *
 * The HC595 is connected to the MCU as follows:
 *  PA2 --> SRCLK (shift clock)
 *  PA1 --> SDIN (shift data in)
 *  PC4 --> RCLK (latch clock)
 *
 * The HD44780 is connected to the HC595 as follows:
 *  QB (bit 1) --> RS
 *  QC (bit 2) --> E
 *  QE (bit 4) --> D4
 *  QF (bit 5) --> D5
 *  QG (bit 6) --> D6
 *  QH (bit 7) --> D7
 * Note: QA, QD and QH' are not used.
 */

/**
 * Set HC595 shift clock state
 * @param val true for high, false for low
 */
static inline void set_595_clock(bool val) {
    // bit 18 is PA2 clear, bit 2 is PA2 set
    GPIOA->BSHR = (1 << 18) | (val ? (1 << 2) : 0);
}

/**
 * Set HC595 shift in data
 * @param val true for high, false for low
 */
static inline void set_595_data(bool val) {
    // bit 17 is PA1 clear, bit 1 is PA1 set
    GPIOA->BSHR = (1 << 17) | (val ? (1 << 1) : 0);
}

/**
 * Set HC595 latch clock state
 * @param val true for high, false for low
 */
static inline void set_595_latch(bool val) {
    // bit 20 is PC4 clear, bit 4 is PC4 set
    GPIOC->BSHR = (1 << 20) | (val ? (1 << 4) : 0);
}

/**
 * Shift a byte in the HC595 shift register and latch it out
 * @param byte the byte to output
 */
void output_byte_595(uint8_t byte) {
    set_595_clock(false);
    set_595_data(false);

    // clock the bits in
    for (int i = 0; i < 8; i++) {
        set_595_data( (byte & 0x80) != 0 );
        set_595_clock(true);
        set_595_clock(false);
        byte <<= 1;
    }

    // latch the byte out
    set_595_latch(true);
    set_595_latch(false);
}

/**
 * Send data/command to the HD44780 display.
 * Note: Only the high nibble of the value is used, the low 4 bits are always sent as 0.
 * @param rs true if data, false if command
 * @param value the value to output
 */
void send_hd44780_register(bool rs, uint8_t value) {
    // pick high nibble of value
    // set or clear bit 1 to select the register
    uint8_t byte = (value & 0xf0) | (rs ? (1 << 1) : 0);
    // output byte with E = 1
    output_byte_595(byte | (1 << 2));
    // output byte with E = 0
    output_byte_595(byte);
}

/**
 * Send a command to the HD44780 display in 4 bit mode
 * @param cmd the command to send
 */
void send_hd44780_command(uint8_t cmd) {
    // output bits 7..4 as command
    send_hd44780_register(false, cmd);
    // output bits 3..0 as command
    send_hd44780_register(false, cmd << 4);
}

/**
 * Send a data byte to the HD44780 display in 4 bit mode
 * @param data the data byte to send
 */
void send_hd44780_data(uint8_t data) {
    // output bits 7..4 as data
    send_hd44780_register(true, data);
    // output bits 3..0 as command
    send_hd44780_register(true, data << 4);
}

/**
 * Initialize the HD44780 display.
 *
 * During initialization, the display controller
 * is first put into 8 bit mode and then to 4 bit mode
 */
void init_hd44780() {
    // allow display some time to power on
    Delay_Ms(100);

    /*
     * Set the controller into 8 bit mode.
     * This can be guaranteed from any state by
     * writing the function set command 3 times
     */
    for (int i=0;i<3;i++) {
        // set 8 bit mode
        send_hd44780_register(false, 0x30);
        // wait maximum command execution time
        Delay_Us(4100);
    }

    // the display is now guaranteed to be in 8 bit mode

    // set 4 bit mode
    send_hd44780_register(false, 0x20);
    // wait for maximum command execution time
    Delay_Us(100);

    /*
     * Display is now guaranteed to be in 4 bit mode.
     * Carry on with proper configuration.
     */

    // set 4 bit interface, 1/16 duty, 5x8 dots
    send_hd44780_command(0b00101000);
    Delay_Us(100);

    // enable display
    send_hd44780_command(0b00001100);
    Delay_Us(100);

    // clear display
    send_hd44780_command(0x01);
    Delay_Us(3000);

    // cursor home
    send_hd44780_command(0x02);
    Delay_Us(3000);
}

/**
 * Move cursor to given position
 * @param pos position to move the cursor to
 */
void set_pos_hd44780(uint8_t pos) {
    send_hd44780_command(0x80 | (pos & 0x7f));
    Delay_Us(100);
}

/**
 * Write character data to CGRAM
 * @param ch character code
 * @param data character bitmap data
 */
void write_cgram_char_hd44780(uint8_t ch, uint8_t data[8]) {
    // write the character data
    for (int i = 0; i < 8; i++) {
        // set CGRAM address
        send_hd44780_command(0x40 | (ch << 3) | i);
        Delay_Us(100);
        send_hd44780_data(data[i]);
        Delay_Us(100);
    }
}

/**
 * Output a character to the HD44780 display
 * @param ch character to send
 * @return the character which was output
 */
int putchar_hd44780(int ch) {
    send_hd44780_data(ch);
    Delay_Us(100);
    return ch;
}

/**
 * Output a string to the HD44780 display
 * @param string string to output
 * @return the value 0
 */
int puts_hd44780(char* string) {
    while(*string) {
        putchar_hd44780(*(string++));
    }
    return 0;
}

/**
 * printf implementation for HD44780 display
 * @param format format string
 * @param ... further arguments
 * @return number of chars printed
 */
int printf_hd44780(char* format, ...) {
    va_list args;
    va_start(args, format);

    char string[128];
    int ret = mini_vsnprintf(string, sizeof(string), format, args);
    va_end(args);

    puts_hd44780(string);

    return ret;
}

/**
 * printf to a given field as right justified
 * If string does not fit field, prints starting at field start position
 * and exceeds field width toward the right.
 * @param pos field start position
 * @param cols width of field
 * @param format format string
 * @param ... further arguments
 * @return number of relevant chars printed
 */
int printf_hd44780_right_justified(uint8_t pos, uint8_t cols, char* format, ...) {
    va_list args;
    va_start(args, format);

    char string[128];
    int ret = mini_vsnprintf(string, sizeof(string), format, args);
    va_end(args);

    set_pos_hd44780(pos);
    if (ret >= cols) {
        puts_hd44780(string);
    } else {
        for(int col=0;col<cols-ret;col++) {
            putchar_hd44780(' ');
        }
        puts_hd44780(string);
    }

    return ret;
}

/**
 * printf to a given field as left justified
 * If string does not fit field, prints starting at field start position
 * and exceeds field width toward the right.
 * @param pos field start position
 * @param cols width of field
 * @param format format string
 * @param ... further arguments
 * @return number of relevant chars printed
 */
int printf_hd44780_left_justified(uint8_t pos, uint8_t cols, char* format, ...) {
    va_list args;
    va_start(args, format);

    char string[128];
    int ret = mini_vsnprintf(string, sizeof(string), format, args);
    va_end(args);

    set_pos_hd44780(pos);
    if (ret >= cols) {
        puts_hd44780(string);
    } else {
        puts_hd44780(string);
        for(int col=0;col<cols-ret;col++) {
            putchar_hd44780(' ');
        }
    }

    return ret;
}

/**
 * History is shown as a graph using 8 characters on the display.
 * Each character has 5 pixel columns, and thus the total history has 40 time intervals.
 * For each interval, the minimum and maximum of recorded parameters is stored.
 * The recorded parameters are the phase error, the frequency error,
 * the OCXO control word and the OCXO temperature.
 *
 * History is kept in two time scales: long and short.
 * In the short scale, the total history is 8 hours. Each character is thus one hour.
 * In the long scale, the total history is 8 days. Each character is thus one day.
 *
 * The history display alternates between the different variables and the time scales.
 */

const unsigned int history_long_length_seconds = 17280; // 4.8 hours of history
const unsigned int history_short_length_seconds = 720; // 12 minutes of history

enum { N_history = 40 }; // number of history intervals

int16_t frequency_history_short_min[N_history];
int16_t frequency_history_short_max[N_history];

int16_t phase_history_short_min[N_history];
int16_t phase_history_short_max[N_history];

int16_t temperature_history_short_min[N_history];
int16_t temperature_history_short_max[N_history];

int16_t satellites_history_short_min[N_history];
int16_t satellites_history_short_max[N_history];

int16_t control_history_short_min[N_history];
int16_t control_history_short_max[N_history];


int16_t frequency_history_long_min[N_history];
int16_t frequency_history_long_max[N_history];

int16_t phase_history_long_min[N_history];
int16_t phase_history_long_max[N_history];

int16_t temperature_history_long_min[N_history];
int16_t temperature_history_long_max[N_history];

int16_t satellites_history_long_min[N_history];
int16_t satellites_history_long_max[N_history];

int16_t control_history_long_min[N_history];
int16_t control_history_long_max[N_history];

// switch display period
const unsigned int display_switch_period_seconds = 10;

int16_t cast_int16_saturate(int value) {
    if (value > INT16_MAX) {
        return INT16_MAX;
    } else if (value < INT16_MIN) {
        return INT16_MIN;
    } else {
        return value;
    }
}

void update_min_max(int16_t* min, int16_t* max, const int16_t value) {
    if (value < *min) {
        *min = value;
    }
    if (value > *max) {
        *max = value;
    }
}

void initialize_min_max(int16_t* min, int16_t* max) {
    *min = INT16_MAX;
    *max = INT16_MIN;
}

void initialize_history(int16_t* history_min, int16_t* history_max) {
    for (int i = 0; i < N_history; i++) {
        initialize_min_max(&history_min[i], &history_max[i]);
    }
}

void roll_history(int16_t* history_min, int16_t* history_max) {
    for (int i = N_history - 1; i > 0; i--) {
        history_min[i] = history_min[i - 1];
        history_max[i] = history_max[i - 1];
    }

    initialize_min_max(&history_min[0], &history_max[0]);
}

int main() {
    SystemInit();

    RCC->APB2PCENR |= RCC_APB2Periph_GPIOA | RCC_APB2Periph_GPIOC;

    // PA1: 595 serial shift data
    GPIOA->CFGLR &= ~(0xf << (4*1));
    GPIOA->CFGLR |= (GPIO_Speed_10MHz | GPIO_CNF_OUT_PP) << (4*1);
    // PA2: 595 serial shift clock
    GPIOA->CFGLR &= ~(0xf << (4*2));
    GPIOA->CFGLR |= (GPIO_Speed_10MHz | GPIO_CNF_OUT_PP) << (4*2);
    // PC4: 595 latch clock
    GPIOC->CFGLR &= ~(0xf << (4*4));
    GPIOC->CFGLR |= (GPIO_Speed_10MHz | GPIO_CNF_OUT_PP) << (4*4);

    init_hd44780();
    i2c_init(0x12, 100000UL);

    // data structure fetched from GNSS interface
    volatile struct __attribute__((packed)) {
        uint32_t timestamp; // unix time of fix.
        int32_t lat; // fraction of 360 degrees in Q0.31 format. North is positive.
        int32_t lon; // fraction of 360 degrees in Q0.31 format. East is positive.
        uint8_t nsat_fix_valid; // bit 7: is valid, bit 6: has fix, bits [5:0] number of satellites
    } iface_data;
    int iface_error;

    // data structure fetched from PLL controller
    volatile struct __attribute__((packed)) {
        int32_t phase_error_raw; // Q7.24, LSB ~= 3.0 fs
        int32_t phase_error_filtered; // Q7.24, LSB ~= 3.0 fs
        int32_t frequency_error_raw; // Q7.24, LSB ~= 29.8 nHz
        int32_t frequency_error_filtered; // Q7.24, LSB ~= 29.8 nHz
        uint32_t time_since_valid; // How many seconds since last control update (i.e. since valid GPS data)
        int16_t ocxo_control_word; // OCXO control word
        uint8_t control_mode; // Which control mode are we in 0=FLL, 1=PLL
    } pfd_data;
    int pfd_error;

    // temperature fetched from the OCXO board
    volatile uint16_t temperature_data;
    int temperature_error;

    uint32_t error_count = 0;

    enum {
        FREQUENCY_SHORT = 0,
        PHASE_SHORT = 1,
        TEMPERATURE_SHORT = 2,
        SATELLITES_SHORT = 3,
        CONTROL_SHORT = 4,
        FREQUENCY_LONG = 5,
        PHASE_LONG = 6,
        TEMPERATURE_LONG = 7,
        SATELLITES_LONG = 8,
        CONTROL_LONG = 9,
        DISPLAY_END
    } display = FREQUENCY_SHORT;

    // initialize the history arrays
    // short
    initialize_history(frequency_history_short_min, frequency_history_short_max);
    initialize_history(phase_history_short_min, phase_history_short_max);
    initialize_history(temperature_history_short_min, temperature_history_short_max);
    initialize_history(satellites_history_short_min, satellites_history_short_max);
    initialize_history(control_history_short_min, control_history_short_max);

    // long
    initialize_history(frequency_history_long_min, frequency_history_long_max);
    initialize_history(phase_history_long_min, phase_history_long_max);
    initialize_history(temperature_history_long_min, temperature_history_long_max);
    initialize_history(satellites_history_long_min, satellites_history_long_max);
    initialize_history(control_history_long_min, control_history_long_max);

    // time at which to switch to the next short history interval
    uint32_t control_history_short_interval_switch_timestamp = 0;

    // time at which to switch to the next long history interval
    uint32_t control_history_long_interval_switch_timestamp = 0;

    // time at which to switch to the next display
    uint32_t display_switch_timestamp = 0;

    while(1) {
        // fetch data from GNSS interface
        i2c_master_transfer(0x03, &iface_data, sizeof(iface_data));
        while(!i2c_master_done());
        iface_error = i2c_master_error();

        // fetch temperature from OCXO board
        i2c_master_transfer(0x0d, &temperature_data, sizeof(temperature_data));
        while(!i2c_master_done());
        temperature_error = i2c_master_error();

        // fetch data from PLL controller
        i2c_master_transfer(0x11, &pfd_data, sizeof(pfd_data));
        while(!i2c_master_done());
        pfd_error = i2c_master_error();

        if (iface_error || temperature_error || pfd_error) {
            error_count++;

            if (error_count > 4) {
                set_pos_hd44780(0x00);
                printf_hd44780("!! I2C ERRORS !!");
                set_pos_hd44780(0x40);
                int line_length = 0;
                if (temperature_error) {
                    puts_hd44780("OCXO ");
                    line_length += 5;
                }
                if (iface_error) {
                    puts_hd44780("GNSS ");
                    line_length += 5;
                }
                if (pfd_error) {
                    puts_hd44780("PFD ");
                    line_length += 4;
                }
                for (; line_length < 16; line_length++) {
                    putchar_hd44780(' ');
                }
            }
        } else {
            error_count = 0;

            // compute ferr as number of millihertz as Q12.3
            int frequency = (pfd_data.frequency_error_filtered * 500LL) / 2097152LL;

            // compute perr as number of nanoseconds as Q12.3
            int phase = (pfd_data.phase_error_filtered * 50LL) / 2097152LL;

            // compute temperature as Q12.3
            int temperature = temperature_data / 2;

            // control word
            int control_word = pfd_data.ocxo_control_word;

            bool valid = (iface_data.nsat_fix_valid & 0x80) != 0;
            bool fix = (iface_data.nsat_fix_valid & 0x40) != 0;

            int satellites = (valid && fix) ? (iface_data.nsat_fix_valid & 0x3f) : 0;

            int time_since_valid = pfd_data.time_since_valid;

            struct utc_time utc;
            utc_from_unix(iface_data.timestamp, &utc);

            // line 1
            if (!valid) {
                printf_hd44780_left_justified(0x00,16,"! No data: %d", time_since_valid);
            } else if (!fix) {
                printf_hd44780_left_justified(0x00,16,"Acq. sat.: %d", time_since_valid);
            } else if (time_since_valid >= 4) {
                printf_hd44780_left_justified(0x00,16,"!! No PPS: %d", time_since_valid);
            } else {
                // cols 0,1,2,3,4,5 are for time
                printf_hd44780_left_justified(0x00,6,"%02d%02d%02d", utc.h, utc.m, utc.s);

                // cols 6,7,8,9,10,11,12,13,14,15 are for alternating display
                if (display == FREQUENCY_SHORT || display == FREQUENCY_LONG) {
                    printf_hd44780_right_justified(0x06,10,"%dmHz", frequency / 8);
                }
                if (display == PHASE_SHORT || display == PHASE_LONG) {
                    if (pfd_data.control_mode == 1) {
                        // only display phase when in phase lock
                        printf_hd44780_right_justified(0x06,10,"%dns", phase / 8);
                    } else {
                        // otherwise just display a placeholder
                        printf_hd44780_right_justified(0x06,10,"--ns");
                    }
                }
                if (display == TEMPERATURE_SHORT || display == TEMPERATURE_LONG) {
                    if (temperature >= 0) {
                        printf_hd44780_right_justified(0x06,10,"%d.%1dC", temperature / 8, (temperature % 8) * 10 / 8);
                    } else {
                        printf_hd44780_right_justified(0x06,10,"-%d.%1dC", (-temperature) / 8, ((-temperature) % 8) * 10 / 8);
                    }
                }
                if (display == SATELLITES_SHORT || display == SATELLITES_LONG) {
                    printf_hd44780_right_justified(0x06,10,"%d sat", satellites);
                }
                if (display == CONTROL_SHORT || display == CONTROL_LONG) {
                    printf_hd44780_right_justified(0x06,10,"%d #", control_word);
                }
            }

            // line 2 cols 0,1,2 is for lock state
            if (pfd_data.control_mode == 0 || !valid || !fix || time_since_valid >= 4) {
                printf_hd44780_left_justified(0x40,3,"unl");
            } else if (pfd_data.control_mode == 1) {
                printf_hd44780_left_justified(0x40,3,"LCK");
            } else {
                printf_hd44780_left_justified(0x40,3,"???");
            }

            // update the short history
            if (iface_data.timestamp >= control_history_short_interval_switch_timestamp) {
                // switch to next history interval
                control_history_short_interval_switch_timestamp = ((iface_data.timestamp + history_short_length_seconds) / history_short_length_seconds) * history_short_length_seconds;

                // shift the history
                roll_history(phase_history_short_min, phase_history_short_max);
                roll_history(frequency_history_short_min, frequency_history_short_max);
                roll_history(temperature_history_short_min, temperature_history_short_max);
                roll_history(satellites_history_short_min, satellites_history_short_max);
                roll_history(control_history_short_min, control_history_short_max);
            }

            // update the long history
            if (iface_data.timestamp >= control_history_long_interval_switch_timestamp) {
                // switch to next history interval
                control_history_long_interval_switch_timestamp = ((iface_data.timestamp + history_long_length_seconds) / history_long_length_seconds) * history_long_length_seconds;

                // shift the history
                roll_history(phase_history_long_min, phase_history_long_max);
                roll_history(frequency_history_long_min, frequency_history_long_max);
                roll_history(temperature_history_long_min, temperature_history_long_max);
                roll_history(satellites_history_long_min, satellites_history_long_max);
                roll_history(control_history_long_min, control_history_long_max);
            }

            if (iface_data.timestamp >= display_switch_timestamp) {
                // switch to next display
                display_switch_timestamp = iface_data.timestamp + display_switch_period_seconds;

                // switch display
                display++;
                if (display >= DISPLAY_END) {
                    display = FREQUENCY_SHORT;
                }
            }

            if (valid && fix && time_since_valid < 4 && pfd_data.control_mode == 1) {
                // update the short history with the current values
                update_min_max(&frequency_history_short_min[0], &frequency_history_short_max[0], cast_int16_saturate(frequency));
                update_min_max(&phase_history_short_min[0], &phase_history_short_max[0], cast_int16_saturate(phase));
                update_min_max(&temperature_history_short_min[0], &temperature_history_short_max[0], cast_int16_saturate(temperature));
                update_min_max(&satellites_history_short_min[0], &satellites_history_short_max[0], cast_int16_saturate(satellites));
                update_min_max(&control_history_short_min[0], &control_history_short_max[0], cast_int16_saturate(control_word));
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

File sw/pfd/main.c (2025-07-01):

#include <stdio.h>
#include <stdarg.h>
#include <stdbool.h>

#include "ch32fun.h"

#include "i2c.h"

/*
 * GPSDO PFD controller software implementation
 *
 * 1. Counts the number of OCXO cycles, thus
 *    tracking the phase of the OCXO output.
 *
 * 2. Receives PPS pulses from the GNSS receiver unit.
 *
 * 3. Receives absolute time information related to each PPS
 *    as data from the GNSS interface.
 *
 * 4. Compares PPS pulse timing to OCXO timing to control
 *    OCXO for accurate time-keeping.
 *
 * 5. Produces a low jitter PPS output.
 *
 * Implements two controllers: FLL and PLL
 * FLL is used initially to quickly tune the OCXO close
 * to the correct frequency, without caring about phase.
 * PLL is then used to keep the OCXO also phase locked to
 * the TAI second.
 *
 * The GNSS PPS is very jittery in the short term.
 * Thus the phase and/or frequency errors are heavily filtered.
 * The used FLL and PLL controllers are purposely designed to work
 * with such filtered error signals.
 *
 * The OCXO runs at 10 MHz, but it is clock doubled to 20 MHz.
 * At each 20 MHz cycle, a tick counter (OCXO phase) is incremented.
 * The low 16 bits of the tick counter are handled via hardware,
 * while during overflow, a 64 bit software counter is incremented.
 *
 * At each PPS pulse rising edge, input capture hardware is used
 * to capture the 16 bit tick counter value at the start of the pulse.
 * The full 64 bit tick count  (OCXO phase) is then computed by adding
 * the 64 bit overflow counter.
 *
 * The PPS pulses need to be additionally validated against
 * erroneous pulses arriving from the GNSS receiver unit
 *
 * Two controllers are implemented: a frequency-locked loop (FLL)
 * controller and a phase-locked loop (PLL) controller.
 *
 * Both controllers average the observed tick error over a number of PPS
 * pulses. From the averaged tick error, a phase error estimate is derived.
 * See https://kiedontaa.blogspot.com/2025/02/on-quantization-errors-and-recovering.html
 * A frequency error estimate is also derived based on the change of the phase error.
 *
 * The FLL controller is used first to tune the OCXO frequency.
 * The FLL starts out with a short averaging period to achieve a quick
 * coarse adjustment of the frequency, and then gradually increases
 * the averaging period to improve the resolution of the frequency error.
 *
 * Once the FLL has converged to a good frequency, a target phase value is sampled
 * and the control is switched to a PLL controller. The PLL controller is based on
 * https://kiedontaa.blogspot.com/2024/07/single-parameter-controller-for-gps.html
 */

// tick counter high bits [63:16], bits 15:0 always 0.
volatile uint64_t tick_high = 0;

// tick value of last PPS pulse
volatile uint64_t last_tick_pps;
// was the last PPS pulse valid
volatile bool last_valid_pps = false;

/**
 * Get the current tick counter value.
 * Try to account for the fact that the full (sw + hw) tick count
 * cannot be read atomically.
 *
 * I'm not absolutely sure that this routine is water tight.
 * If the TIM1 overflow happens at just the right time,
 * it might be possible to produce an incorrect tick count
 */
uint64_t get_current_tick(void) {
    __disable_irq();
    uint16_t hw_tick = TIM1->CNT;
    uint64_t sw_tick = tick_high;
    uint16_t tim1_intfr = TIM1->INTFR;
    uint16_t hw_tick_late = TIM1->CNT;
    __enable_irq();

    // check if the TIM1 overflow was set
    if (tim1_intfr & TIM_UIF) {
        /*
         * The overflow could have occurred at three critical times:
         *  1. After interrupts disabled, but before hw_tick read
         *  2. After hw_tick read, but before/during sw_tick read
         *  3. After sw_tick read
         *
         * For cases 2 and 3, we have hw_tick_late < hw_tick.
         * In those cases hw_tick is consistent with sw_tick,
         * as hw_tick represents the pre-overflow value and
         * the ISR for updating the sw_tick hasn't executed yet.
         *
         * In case 1, however, hw_tick represents the post-overflow
         * value, but sw_tick represents a pre-overflow value.
         */

        if (hw_tick < hw_tick_late) {
            sw_tick += 65536;
        }
    }

    return sw_tick + hw_tick;
}

/*
 * I2C slave receive (push to us)
 */

/*
 * The variables below represent the latest fully received values.
 * These values get updated once an entire I2C transfer to us is complete.
 */
volatile uint32_t last_timestamp = 0; // last received timestamp value
volatile bool last_timestamp_valid = false; // was the last received timestamp valid

// data structure for pushing data to us
volatile struct {
    uint32_t timestamp; // unix time stamp
    uint8_t valid; // 1 = time stamp is valid, otherwise time stamp is invalid
} __attribute__((packed)) rx_data_buf;

// tick value of last received timestamp information
volatile uint64_t last_timestamp_tick = 0;

// called when someone has pushed data to us
void rx_done_callback(void) {
    last_timestamp_tick = get_current_tick();

    // double buffer the data so that it changes atomically
    last_timestamp = rx_data_buf.timestamp;
    last_timestamp_valid = rx_data_buf.valid == 1;
}

/*
 * I2C slave transmit (pulled from us)
 */

/*
 * The variables below represent the latest values to be transmitted.
 * These values are used to construct the I2C transfer data when requested.
 */
volatile int32_t ui_phase_error_raw; // raw phase error after a cycle, 3.0 fs res.
volatile int32_t ui_phase_error_filtered; // filtered phase error, 3.0 fs res.
volatile int32_t ui_frequency_error_raw; // raw frequency error after a cycle, 29.8 nHz res.
volatile int32_t ui_frequency_error_filtered; // filtered phase error, 29.8 nHz res.
volatile uint64_t ui_tick_valid; // tick of latest OCXO control update
volatile int16_t ui_ocxo_control_word; // last OCXO control word
volatile uint8_t ui_control_mode; // controller mode at last update, 0=FLL, 1=PLL

// data structure for pulling data from us
volatile struct {
    int32_t phase_error_raw; // Q7.24, LSB ~= 3.0 fs
    int32_t phase_error_filtered; // Q7.24, LSB ~= 3.0 fs
    int32_t frequecy_error_raw; // Q7.24, LSB ~= 29.8 nHz
    int32_t frequency_error_filtered; // Q7.24, LSB ~= 29.8 nHz
    uint32_t time_since_valid; // How many seconds since last control update (i.e. since valid GPS data)
    int16_t ocxo_control_word; // OCXO control word
    uint8_t control_mode; // Which control mode are we in 0=FLL, 1=PLL
} __attribute__((packed)) tx_data_buf;
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

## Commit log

2024-05-19 iface: use common I2C functions, separate data for push and pull push: timestamp value as soon as it arrives with validity pull: timestamp, latitude, longitude and number of satellites with validity
2024-05-25 Add querying for master transfer errors
    [i2c.c]
2024-05-25 ocxo: Switch to using common code base for I2C
2024-05-25 Switch to using common code base for I2C. Control update: Use first an FLL, then a fast PLL and finally a slow PLL. Provide status data via I2C when pulled.
2025-02-22 common/i2c: Differentiate between errors, rename acquire and release calls
    [i2c.c]
2025-02-22 common/i2c: Improve code quality and documentation
2025-02-22 pfd: Add phase bias correction
    [main.c]
2025-03-15 pfd: Change control approach. Instead of fast control period with low-pass filtered inputs, use a slow control period with inputs averaged in between.
2025-03-15 Add electronics design files
    [clkbuf.kicad_sch, gps_board.kicad_pcb, gps_board.kicad_sch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]
2025-03-15 Add mechanical files
    [bottom_plate.stl, box_bottom.stl, box_lid.stl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]
2025-07-01 pfd: Revise control, revise phase estimation, improve documentation Control, FLL: Use estimated phase, instead of ticks, to compute frequency. Revise logic for switching averaging period. Control, PL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
2026-06-23 lcd: Add long and short history graphs of multiple parameters
    [main.c]
